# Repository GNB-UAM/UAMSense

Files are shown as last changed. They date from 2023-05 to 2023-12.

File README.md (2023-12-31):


# UAMSense electronic nose design
Artificial nose design with multimodal sensing capabilities.

___These are experimental designs. Use at your own risk.___

Please see Bibtex and other citation options at the bottom of the page.

UAMSense 4
==========

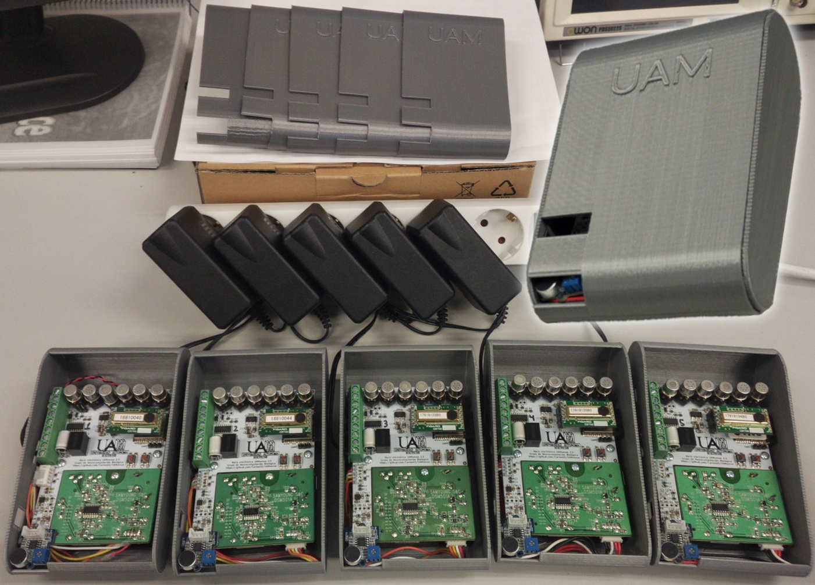
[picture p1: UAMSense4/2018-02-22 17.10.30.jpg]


UAMSense 3
==========

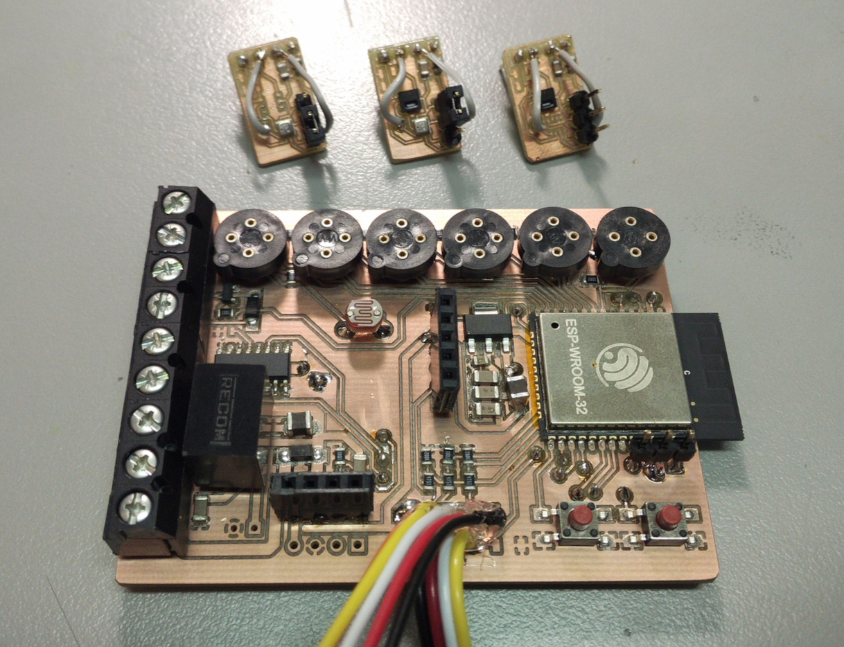
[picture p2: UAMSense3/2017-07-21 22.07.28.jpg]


UAMSense 2
==========

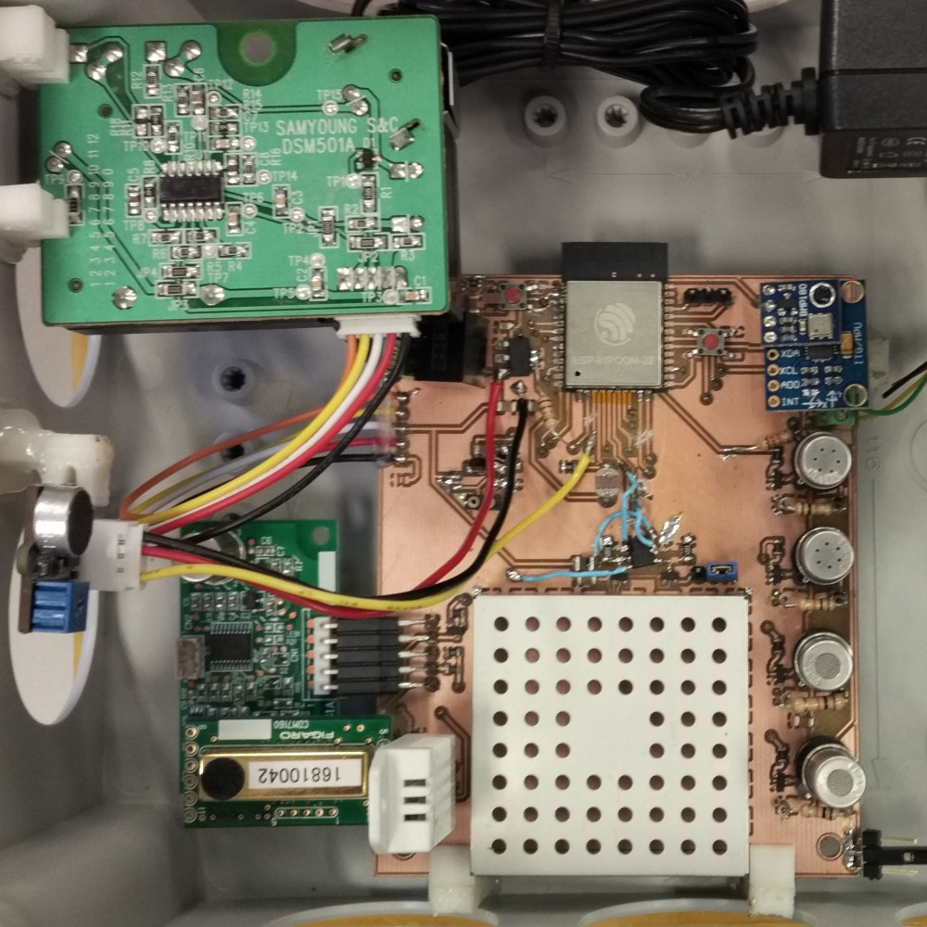
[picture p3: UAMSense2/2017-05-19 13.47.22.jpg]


UAMSense 1
==========

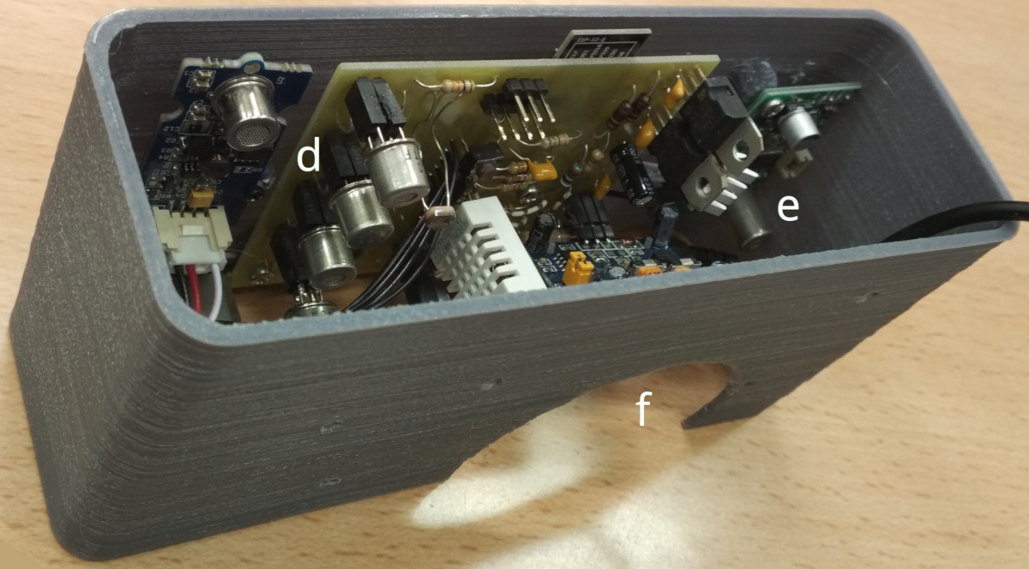
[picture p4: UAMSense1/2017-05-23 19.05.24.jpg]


UART-BME680
===========

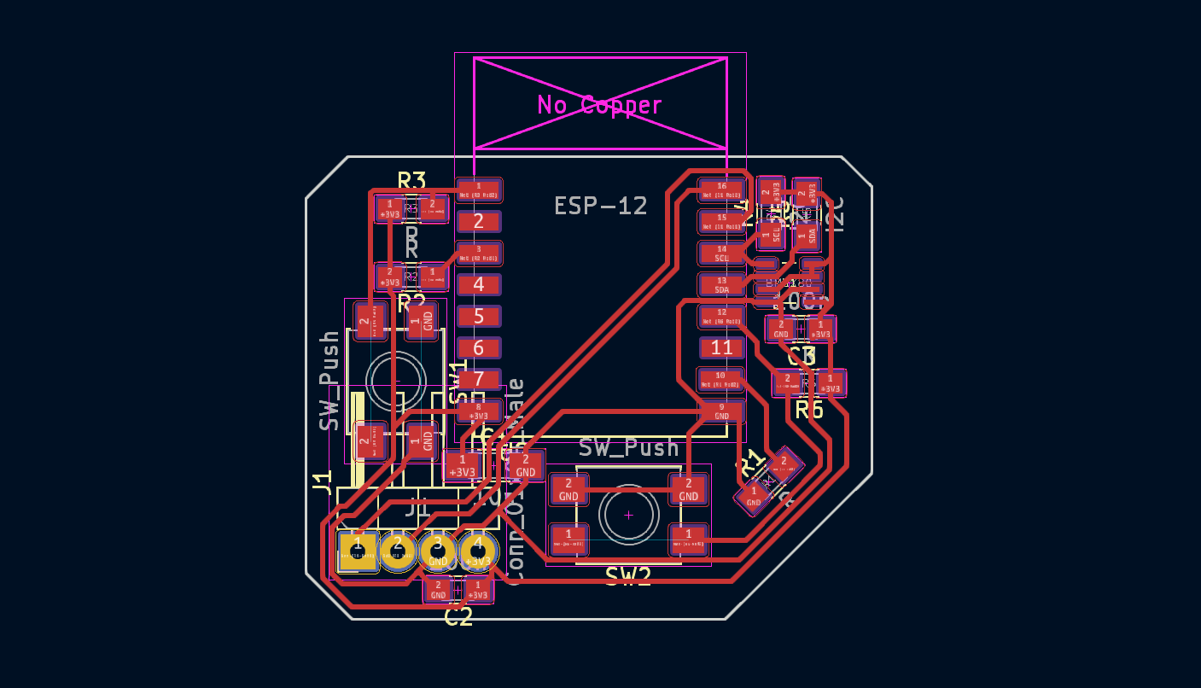
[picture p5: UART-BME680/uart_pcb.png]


I2C-Sensors
===========

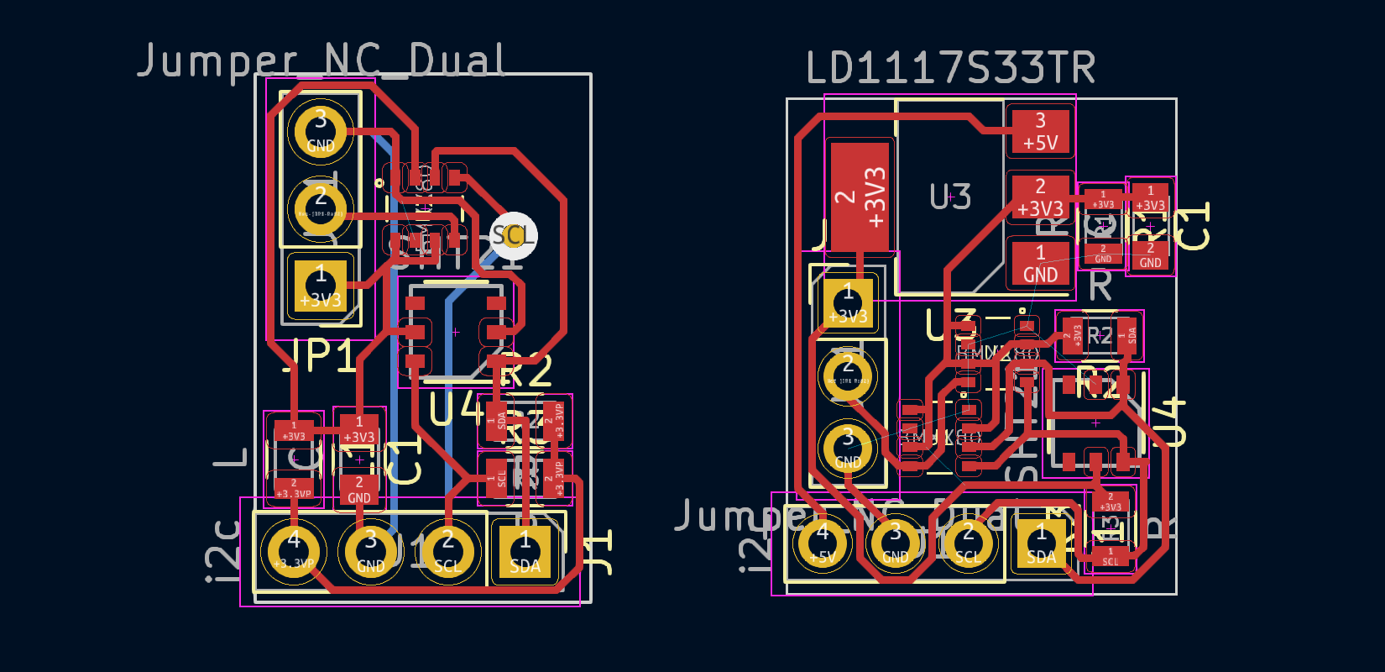
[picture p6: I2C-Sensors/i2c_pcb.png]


License
=======
For source code: GPLv3 <https://www.gnu.org/licenses/gpl-3.0.en.html>

For hardware: Attribution-ShareAlike 4.0 International <https://creativecommons.org/licenses/by-sa/4.0/>

© Carlos Garcia-Saura 2023

Cite as
=======

Scientific papers:
- Garcia-Saura C., Rodriguez-Lujan I., Serrano E., Rodríguez F.B. and Varona P., At-home monitorization using artificial noses
and multimodal sensors: a noninvasive approach to human routine certification. IBJ Plus 2022 1(s5) e00017. DOI: 10.24217/2531-
0151.22v1s5.00017. https://doi.org/10.24217/2531-0151.22V1S5.00017

PhD Thesis:
```bibtex
@phdthesis{garciasaura2023,
  title={Exploration and characterization of environments under uncertainty using multimodal sensors},
  author={Garcia-Saura, Carlos},
  year={2023},
  school={Escuela Politecnica Superior, Universidad Autonoma de Madrid}
}
```

UAMSense project (this repository):
```bibtex
@misc{uamsense2023,
  author = {Garcia-Saura, Carlos},
  title = {UAMSense electronic nose design},
  publisher = {GitHub},
  year = {2023},
  doi = {10.5281/ZENODO.10442698},
  url = {https://doi.org/10.5281/zenodo.10442698}
}
```

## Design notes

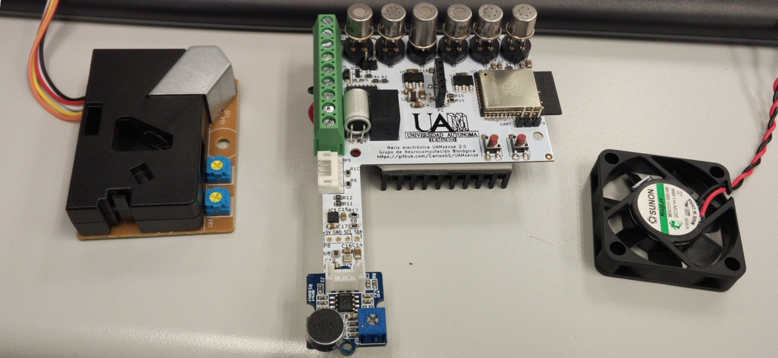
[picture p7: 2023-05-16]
UAMSense4/2017-09-22 19.42.48.jpg

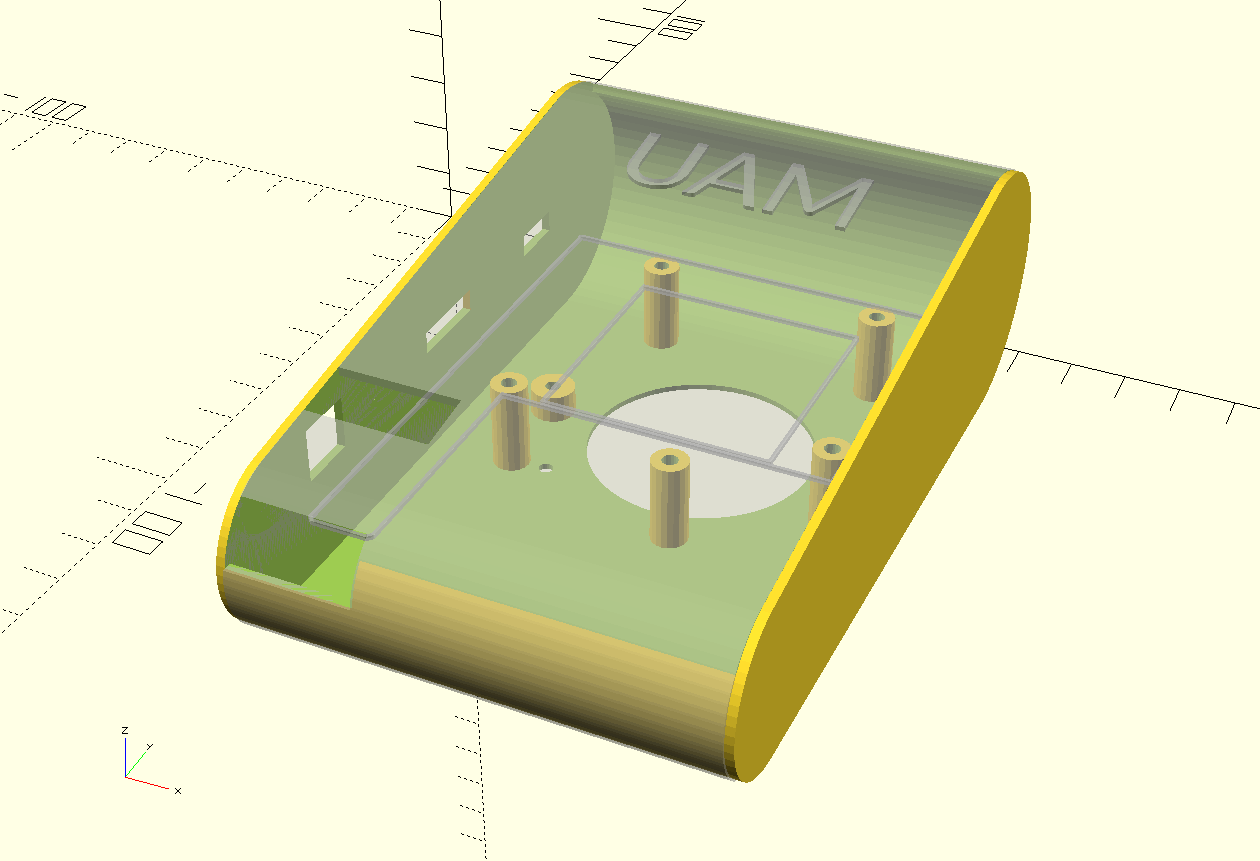
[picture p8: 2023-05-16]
UAMSense4/3Dprinted_enclosure/enclosure3D.png

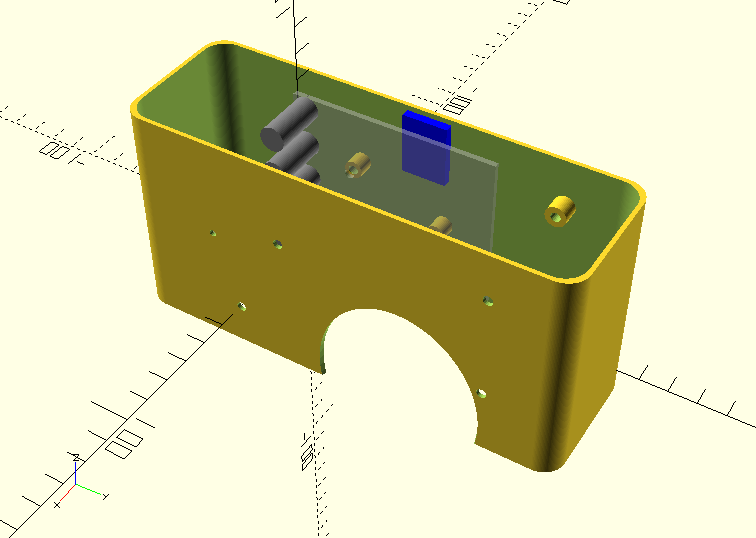
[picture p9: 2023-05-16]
UAMSense1/3Dprinted_enclosure/case.png

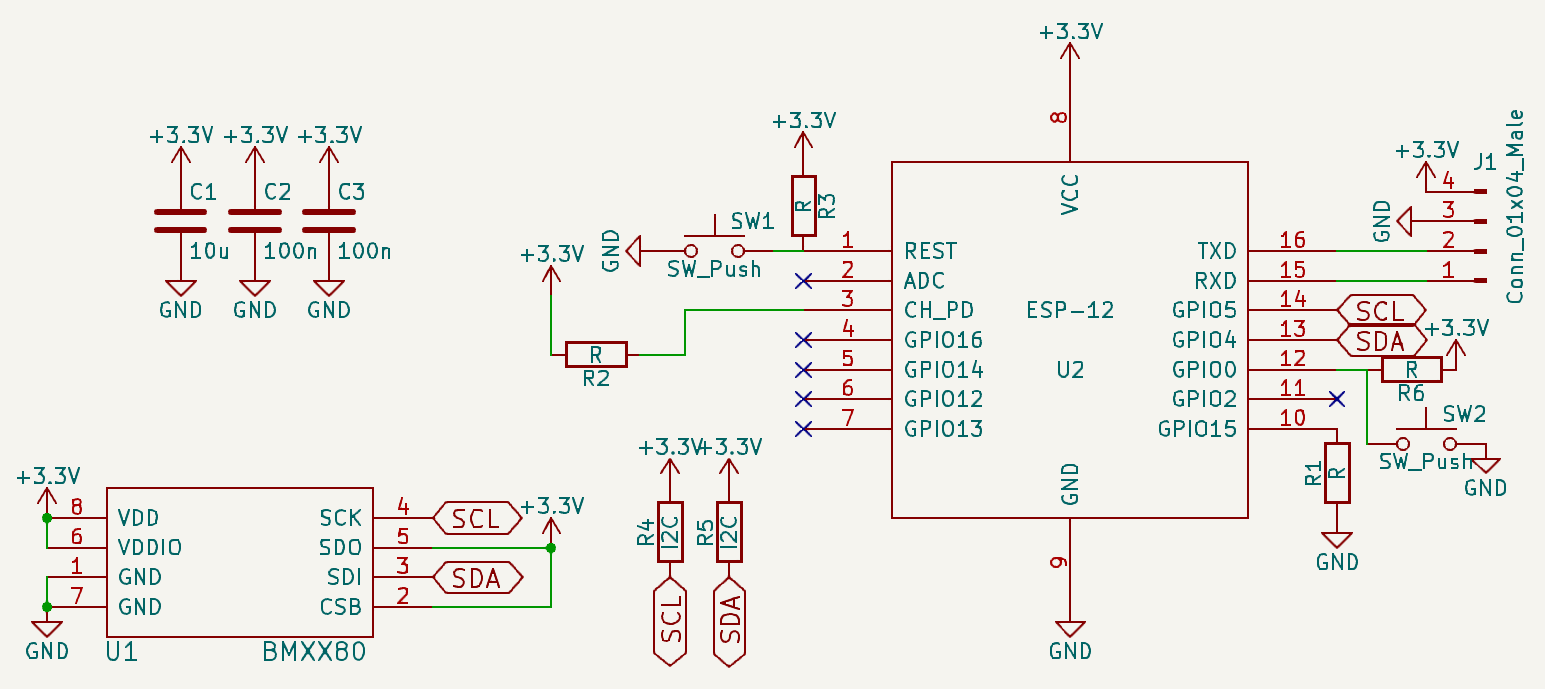
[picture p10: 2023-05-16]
UART-BME680/uart_sch.png

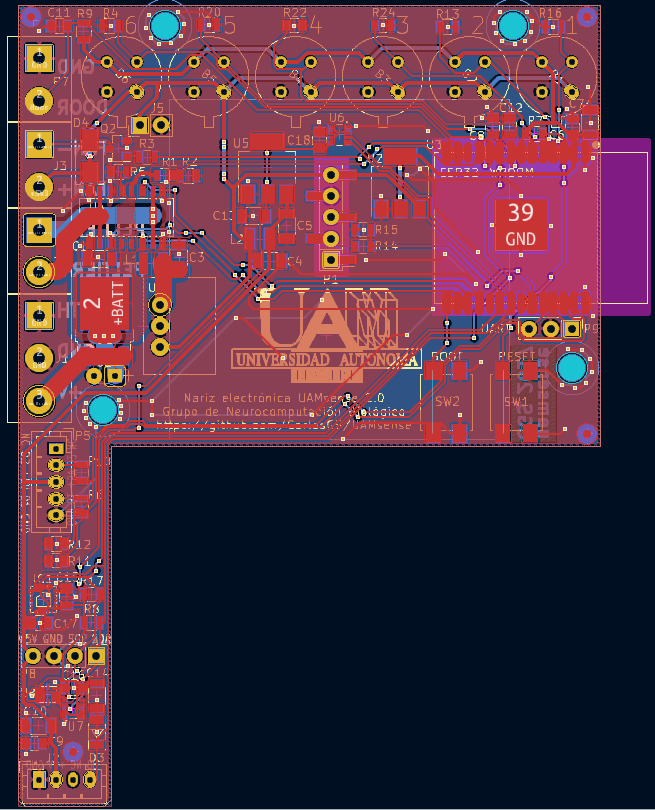
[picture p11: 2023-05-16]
UAMSense4/uamsense4_pcb.png

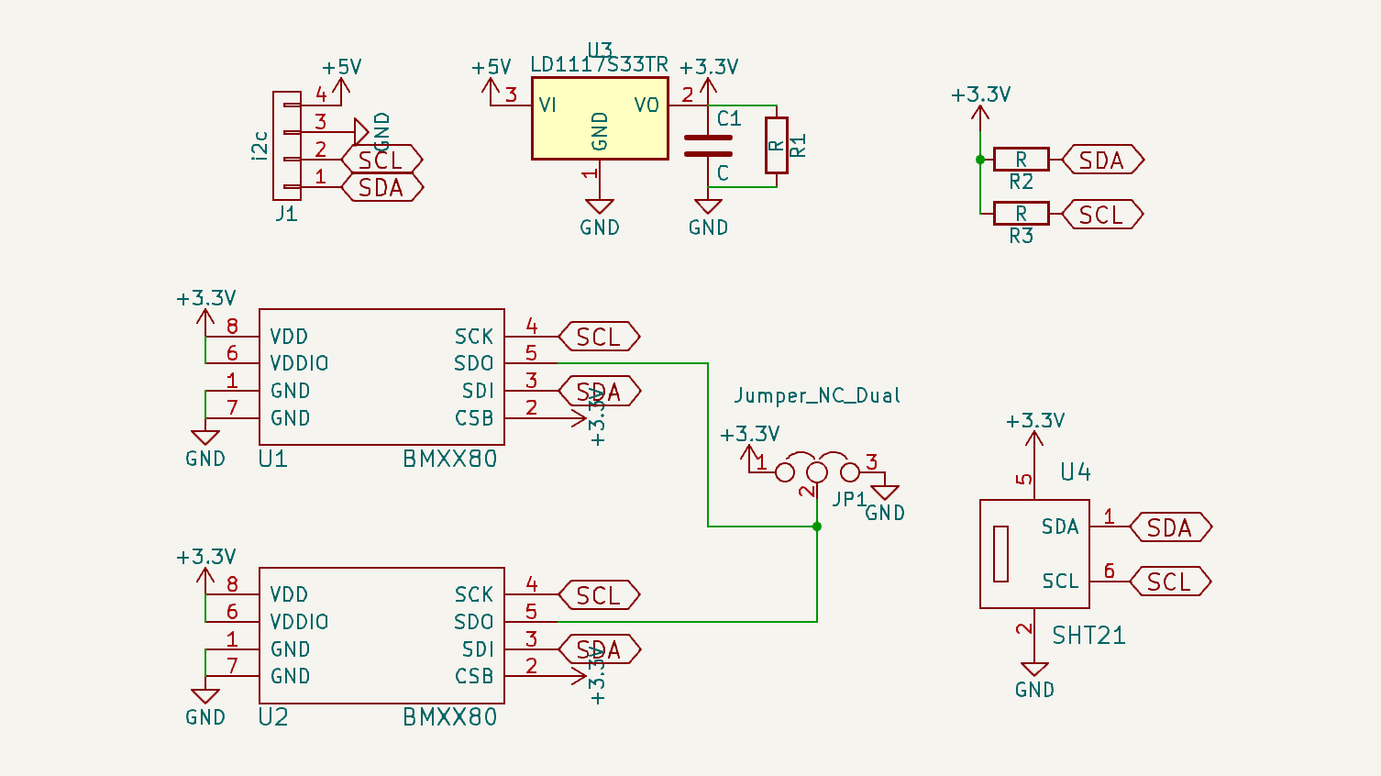
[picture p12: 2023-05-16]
I2C-Sensors/i2c_sch.png

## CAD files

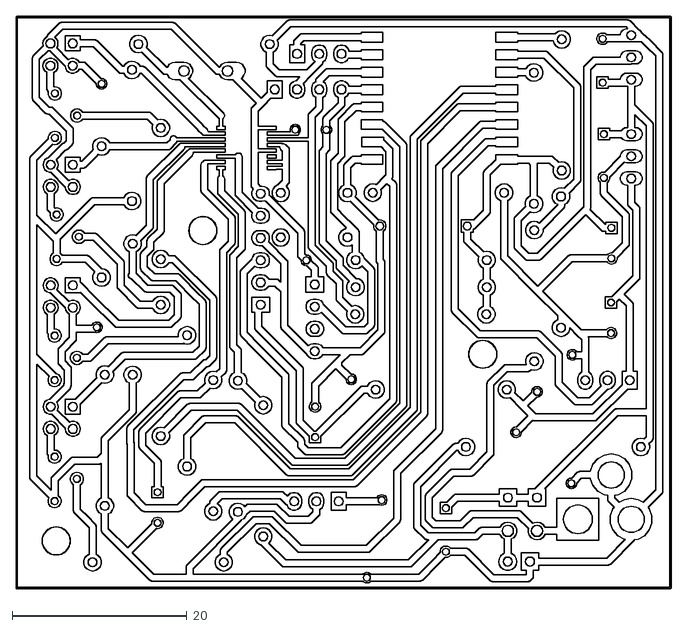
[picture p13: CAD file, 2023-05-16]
UAMSense1/3Dprinted_enclosure/sensors-B.Cu.dxf
74.9 x 65.4

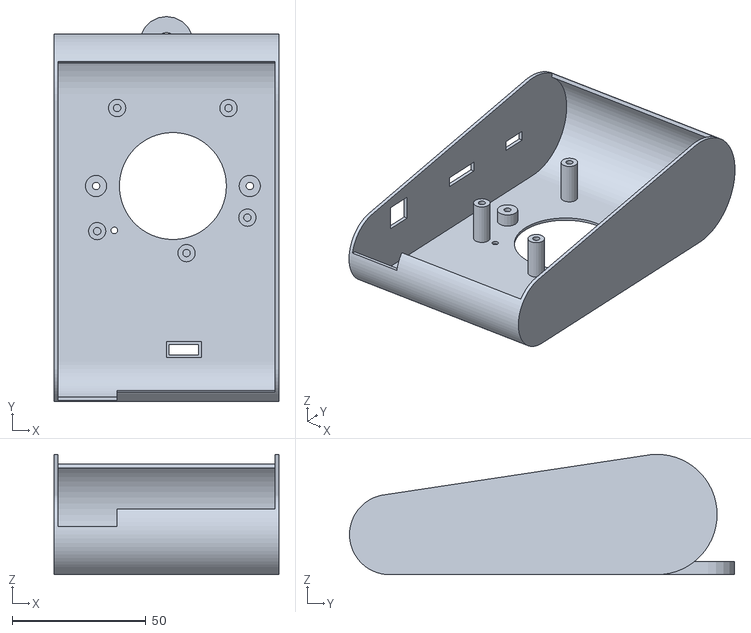
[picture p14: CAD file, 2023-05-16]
UAMSense4/3Dprinted_enclosure/enclosure.stl
84.0 x 144.0 x 45.0

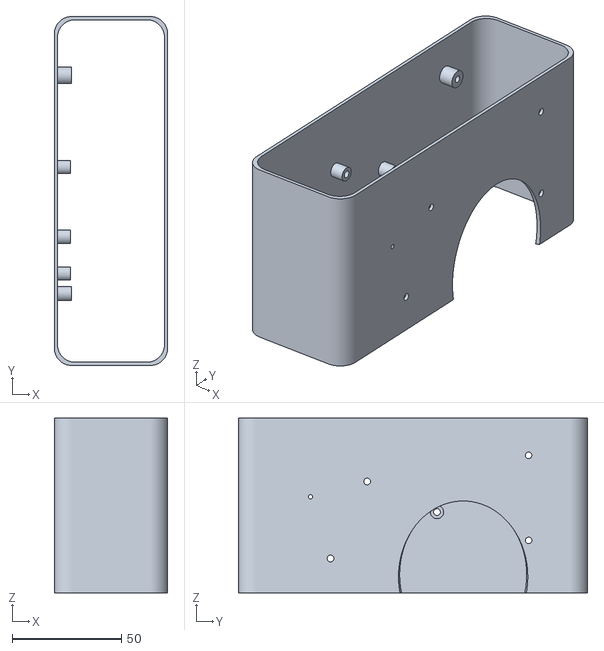
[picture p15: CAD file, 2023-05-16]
UAMSense1/3Dprinted_enclosure/case.stl
52.0 x 160.0 x 80.0

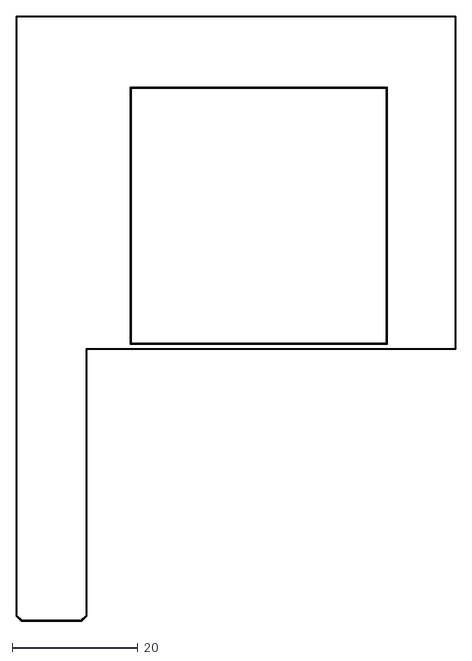
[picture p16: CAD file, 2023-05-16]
UAMSense4/3Dprinted_enclosure/uamsense-Edge.Cuts.dxf
69.8 x 96.0

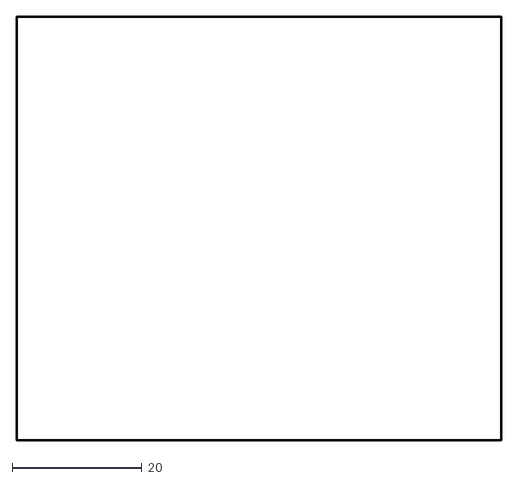
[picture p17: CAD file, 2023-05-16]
UAMSense1/3Dprinted_enclosure/sensors-Edge.Cuts.dxf
74.9 x 65.4

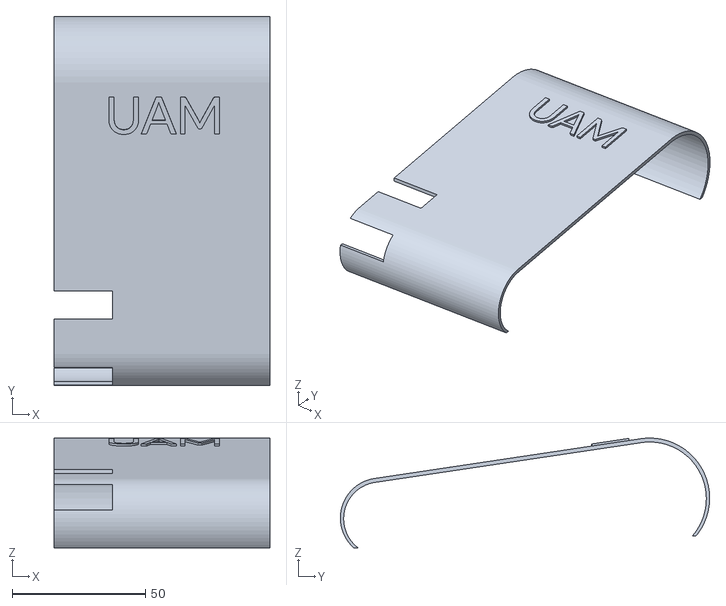
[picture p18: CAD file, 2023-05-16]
UAMSense4/3Dprinted_enclosure/lid.stl
81.0 x 138.5 x 41.2

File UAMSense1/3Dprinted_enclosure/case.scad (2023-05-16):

// UAMSense https://github.com/GNB-UAM/UAMSense
// (C) Carlos Garcia-Saura 2023

// Increase the resolution of default shapes
$fa = 5; // Minimum angle for fragments [degrees]
$fs = 0.5; // Minimum fragment size [mm]




module translate_mainBoard(move = true) {
    if(move)
    translate([0,74,0])
    rotate([0,0,90]) rotate([90,0,0])
    translate([-114,94,0])
    children();
    else children();
}

module pir_hole() {
    // hole for the PIR sensor
    translate_mainBoard(true)
    translate([93+12,-67,3]) rotate([30,0,0]) cylinder(r1=30/2, r2=90/2, h=100);
}

module mainBoard(drills = false, move=true, incD=0, incH=0, drillH=30, centerDrills=false) {
    translate_mainBoard(move)
    if(!drills) {
        //color("black") translate([0,0,3]) import("sensors-B.Cu.dxf");
        
        // ESP12
        color("blue") translate([80,-45,-3]) cube([16,22,3]);
        
        // TGS sensors
        color("gray") translate([44.8,-32.5,2]) cylinder(r=9/2, h=20);
        color("gray") translate([44.8,-32.5-13.9,2]) cylinder(r=9/2, h=20);
        color("gray") translate([44.8,-32.5-13.9*2,2]) cylinder(r=9/2, h=20);
        color("gray") translate([44.8,-32.5-13.9*3,2]) cylinder(r=9/2, h=20);
        
        difference() {
            hull() linear_extrude(height=2) import("sensors-Edge.Cuts.dxf");
            mainBoard(drills = true, move=false, incD=incD, incH=incH);
        }
    } else {
        translate([44.2,-88.3,3+incH]) rotate([180,0,0]) cylinder(h=drillH, r=incD+3.1/2, center=centerDrills);
        translate([61,-53,3+incH]) rotate([180,0,0]) cylinder(h=drillH, r=incD+3.1/2, center=centerDrills);
        translate([93,-67,3+incH]) rotate([180,0,0]) cylinder(h=drillH, r=incD+3.1/2, center=centerDrills);
    }
}

%mainBoard();

difference() {
    union() {
        difference() {
            translate([18,42,30]) bcube([52,160,80],cr=8,cres=30);
            translate([18,42,30]) bcube([52-3,160-3,81],cr=8,cres=30);
        }
        // Drill supports
        mainBoard(drills=true, incD=1.5, incH=-3.5, drillH=6);
        // air quality sensor
        translate([0,-5,34]) rotate([0,-90,0]) cylinder(h=7, r=2+2.5/2);
        // co2
        translate([0,95,14]) {
            rotate([0,-90,0]) cylinder(h=7, r=2+3.5/2);
            translate([0,0,39])
            rotate([0,-90,0]) cylinder(h=7, r=2+3.5/2);
        }
    }
    
    mainBoard();
    mainBoard(drills=true, centerDrills=true, drillH=150);
    pir_hole();

    // Hole for the dust sensor
    %translate([-5,-34]) cube([46.5, 32, 20]);

    // Drill for the air quality sensor
    translate([0,-5,34]) rotate([0,90,0]) cylinder(h=150, r=2/2, center=true);

    // Drills for the CO2 sensor
    translate([0,95,14]) {
        rotate([0,90,0]) cylinder(h=150, r=3/2, center=true);
        translate([0,0,39])
        rotate([0,90,0]) cylinder(h=150, r=3/2, center=true);
    }
}
    


// bcube module by Obijuan http://www.iearobotics.com/wiki/index.php?title=Objeto_3D:Cubo_Biselado
module bcube(size,cr=0,cres=0)
{
  //-- Internal cube size
  bsize = size - 2*[cr,cr,0];

  //-- Get the (x,y) coorner coordinates in the 1st cuadrant
  x = bsize[0]/2;
  y = bsize[1]/2;

  //-- A corner radius of 0 means a standar cube!
  if (cr==0)
    cube(bsize,center=true);
  else {

      
      //-- The height of minkowski object is double. So
      //-- we sould scale by 0.5
      scale([1,1,0.5])

      //-- This translation is for centering the minkowski objet
      translate([-x, -y,0])

      //-- Built the  beveled cube with minkowski
      minkowski() {

        //-- Internal cube
        cube(bsize,center=true);

        //-- Cylinder in the corner (1st cuadrant)
        translate([x,y, 0])
          cylinder(r=cr, h=bsize[2],center=true, $fn=4*(cres+1));
      }
  }

}

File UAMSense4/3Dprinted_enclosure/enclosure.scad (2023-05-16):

// UAMSense https://github.com/GNB-UAM/UAMSense
// (C) Carlos Garcia-Saura 2023

%translate([0,0,16]) linear_extrude(height=0.8) offset(0.25) import("uamsense-Edge.Cuts.dxf"); 

$fn=20;

screw_radius = 2.8/2;

module board_pillars(r=3.2/2, h=10) {
    translate([58.039, -24.232]) cylinder(r=r, h=h);
    translate([99.695, -24.257]) cylinder(r=r, h=h);
    translate([50.576, -70.272]) cylinder(r=r, h=h);
    translate([106.756, -65.227]) cylinder(r=r, h=h);
    
    translate([110-26, -74.5-4]) cylinder(r=r, h=h-0.5);
}

module fan_pillars(r=3.2/2, h=10) {
    translate(fan_center) {
        translate([57.5/2,0,0]) cylinder(r=r, h=h);
        translate([-57.5/2,0,0]) cylinder(r=r, h=h);
    }
}

module fan_pillars_(r=3.2/2, h=10) {
    translate(fan_center)
        for(i = [0:3])
            rotate([0,0,i*90])
                translate([45.5/2,0,0]) cylinder(r=r, h=h);
}

fan_center = [78.9,-53.4,0];





module box() {
    difference() {
        union() {
            hull() {
                translate([34.5,-19,45/2-1]) rotate([0,90,0]) cylinder(r=45/2, h=84, $fn=60);
                translate([34.5,-103-16,30/2-1]) rotate([0,90,0]) cylinder(r=30/2, h=84, $fn=60);
            }
            translate([34.5+84/2,-20,-1]) hull() {
                cylinder(r=20/2,h=5);
                translate([0,20,0]) cylinder(r=20/2,h=5);
            }
        }
        hull() {
            translate([35+1,-19,45/2-1.25+0.01]) rotate([0,90,0]) cylinder(r=45/2-1.25, h=83-2, $fn=60);
            translate([35+1,-103-16,30/2-1.25+0.01]) rotate([0,90,0]) cylinder(r=30/2-1.25, h=83-2, $fn=60);
        }
        translate([34.5+84/2,0,-1-0.1]) cylinder(r=8/2,h=5.2);
    }
}

module lid() {
    elongation = 0.5;
    difference() {
        hull() {
            translate([34.5+1.5,-19+elongation,45/2-1]) rotate([0,90,0]) cylinder(r=45/2, h=84-3, $fn=60);
            translate([34.5+1.5,-103-16-elongation,30/2-1]) rotate([0,90,0]) cylinder(r=30/2, h=84-3, $fn=60);
        }
        hull() {
            translate([34,-19+elongation,45/2-1.25+0.01]) rotate([0,90,0]) cylinder(r=45/2-1.25, h=85, $fn=60);
            translate([34,-103-16-elongation,30/2-1.25+0.01]) rotate([0,90,0]) cylinder(r=30/2-1.25, h=85, $fn=60);
        }
        translate([35.9,-109.5,24]) cube([22,10.5,30]); // Hole for light sensor (top)
        translate([35.9,-140,17]) cube([22,30,9.5]); // Hole for microphone
        translate([75,-65,-15]) rotate([2,0,0]) cube([150,200,40],center=true);
    }
    translate([55,-40,40.8]) rotate([8.5,0,0]) linear_extrude(height = 1)
        text("UAM", font = "Lato Medium", size = 14, direction = "ltr", spacing = 1 );
}

difference() {
    union() {
        box();
        board_pillars(r=6.5/2, h=16);
        fan_pillars(r=8/2, h=5);
        translate([51.5+25,-117.6,0]) cube([13,6,0.5]); // dust sensor air inlet
    }
    translate([0,0,6]) board_pillars(r=screw_radius, h=16);
    translate([0,0,-2]) fan_pillars(r=screw_radius, h=9);
    translate([51.5+26,-116.6,-2]) cube([11,4,4]); // dust sensor air inlet
    
    translate([57,-70,-2]) cylinder(r=2.5/2, h=6); // Hole for fan cable
    translate([0,0,-2]) translate(fan_center) cylinder(r=40/2, h=6, $fn=60); // Hole for fan
    translate([36,-140,17]) cube([22,30,9.5]); // Hole for microphone
    translate([25,-109.5,17]) cube([21.5,10.5,9.5]); // Hole for light sensor (bottom)
    difference() { // holes for cables
        translate([30,-72,19]) cube([15,46,4]);
        translate([29,-72+3*46/9,18]) cube([17,4*46/9,6]);
    }
    hull() { // hole for lid
            translate([35+1,-19,45-1-0.6]) rotate([0,90,0]) cylinder(r=25/2, h=83-2, $fn=60);
            translate([35+1,-103-16,30-1-0.6]) rotate([0,90,0]) cylinder(r=25/2, h=83-2, $fn=60);
    }
}

%lid();

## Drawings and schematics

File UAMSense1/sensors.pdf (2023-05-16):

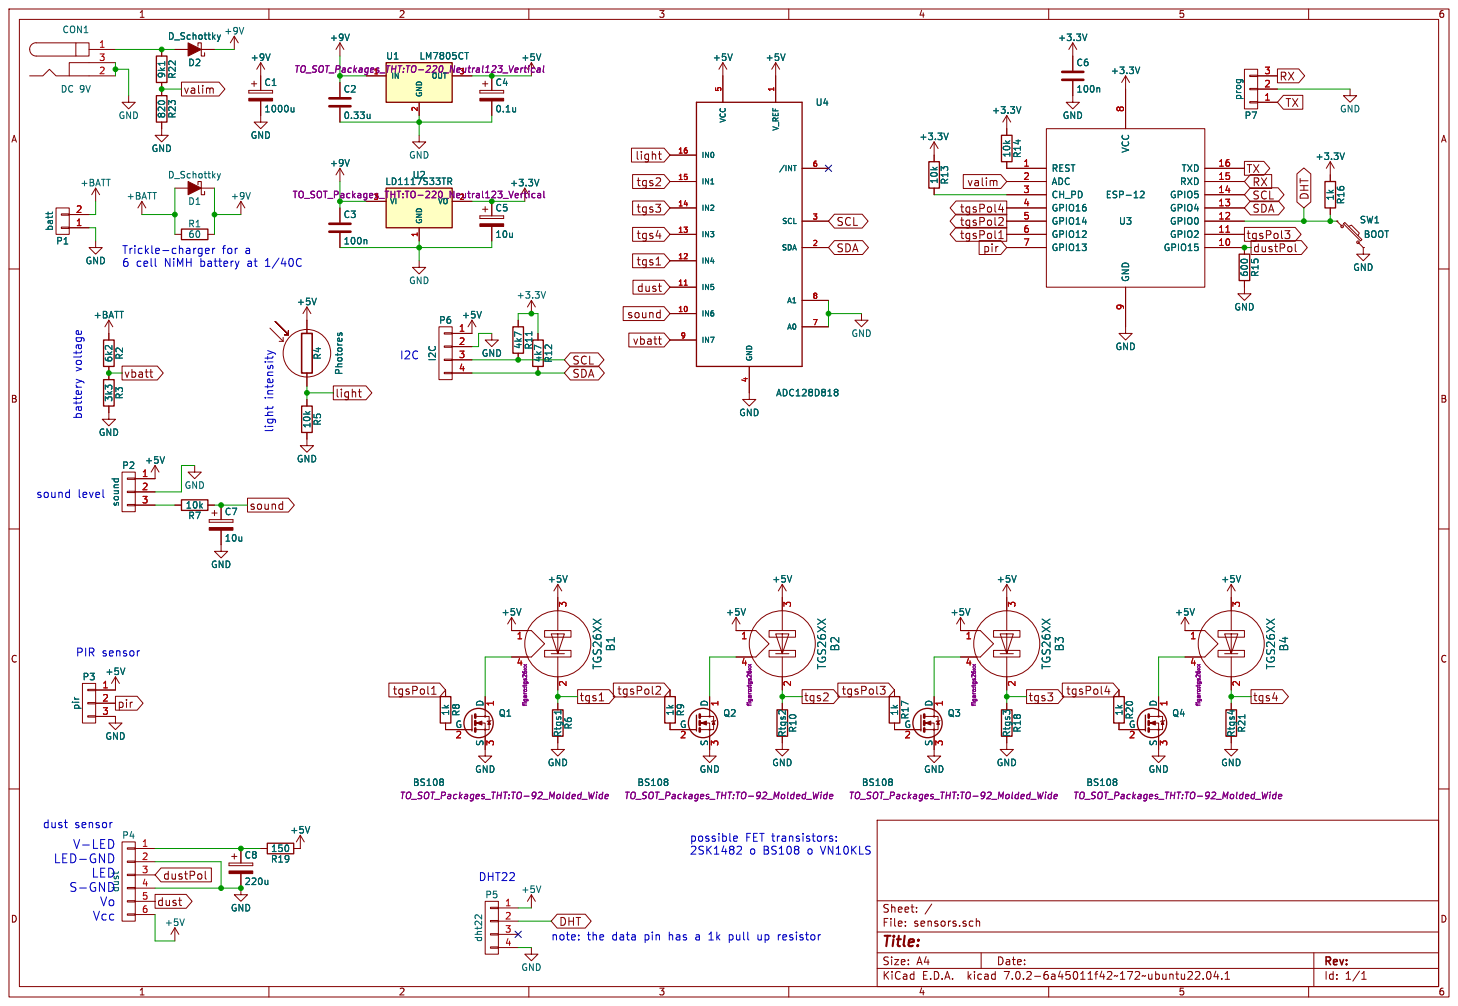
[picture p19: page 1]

6 cell NiMH battery at 1/40C

3 GND GND 1kR9 +5V R18 Rtgs3 GND R17 1k GND Q3 BS108 TO_SOT_Packages_THT:TO-92_Molded_Wide D

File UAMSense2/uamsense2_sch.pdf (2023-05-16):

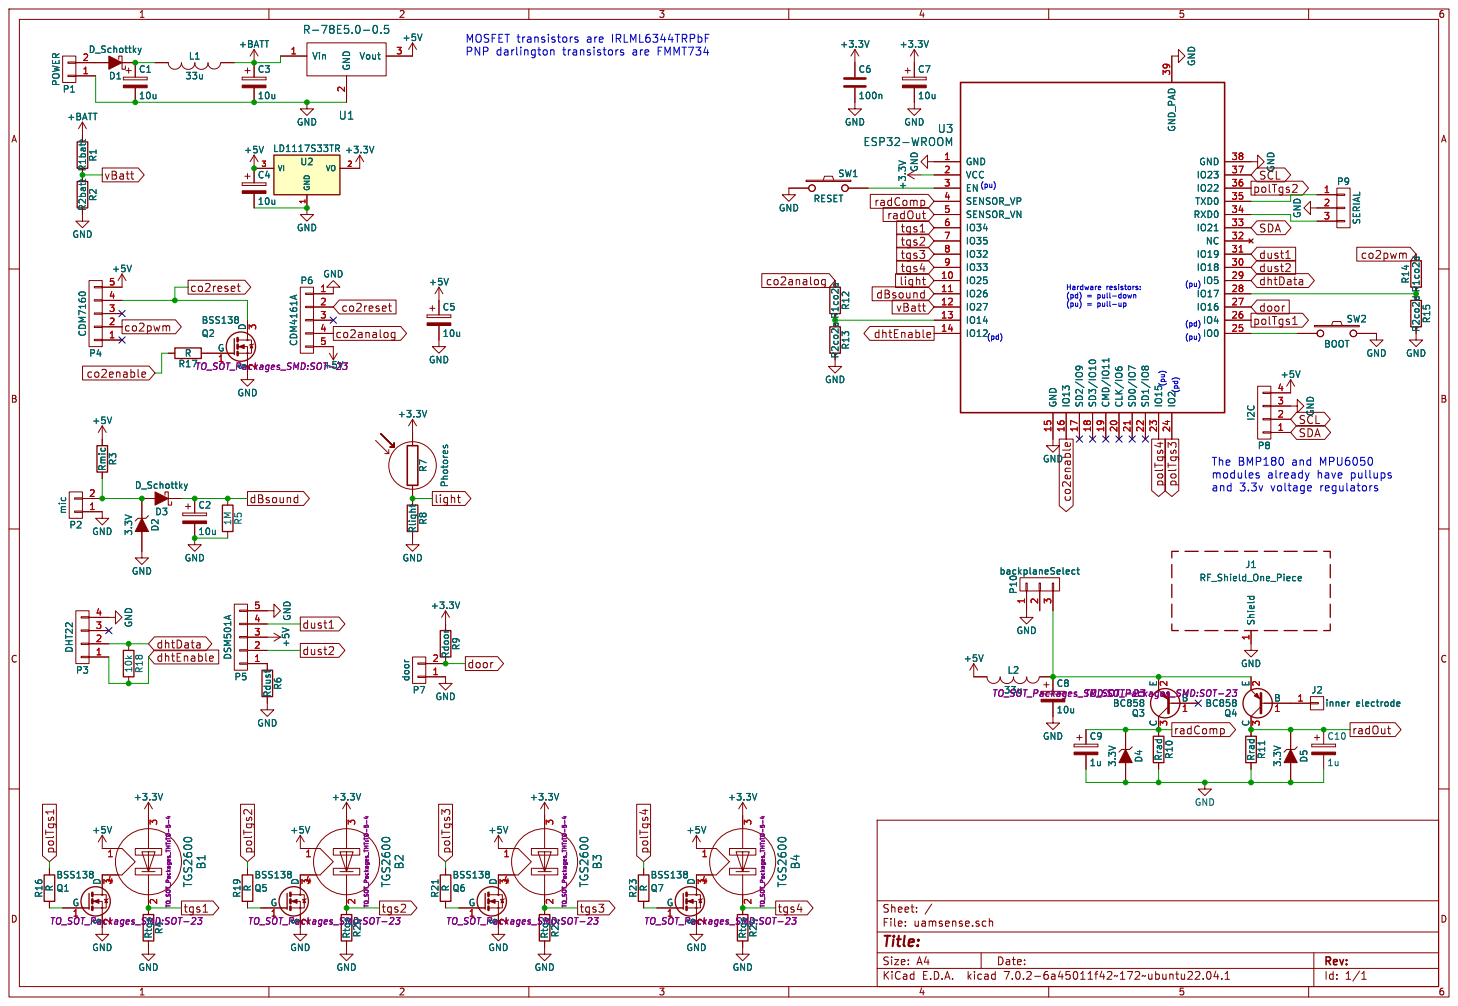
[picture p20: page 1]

3 +5V R23R GNDRtgs R22 Rtgs R24 GND GND

4 Q6 BSS138 TO_SOT_Packages_SMD:SOT-23 G
Id: 1/1 Title: File: uamsense.sch Sheet: / R21R

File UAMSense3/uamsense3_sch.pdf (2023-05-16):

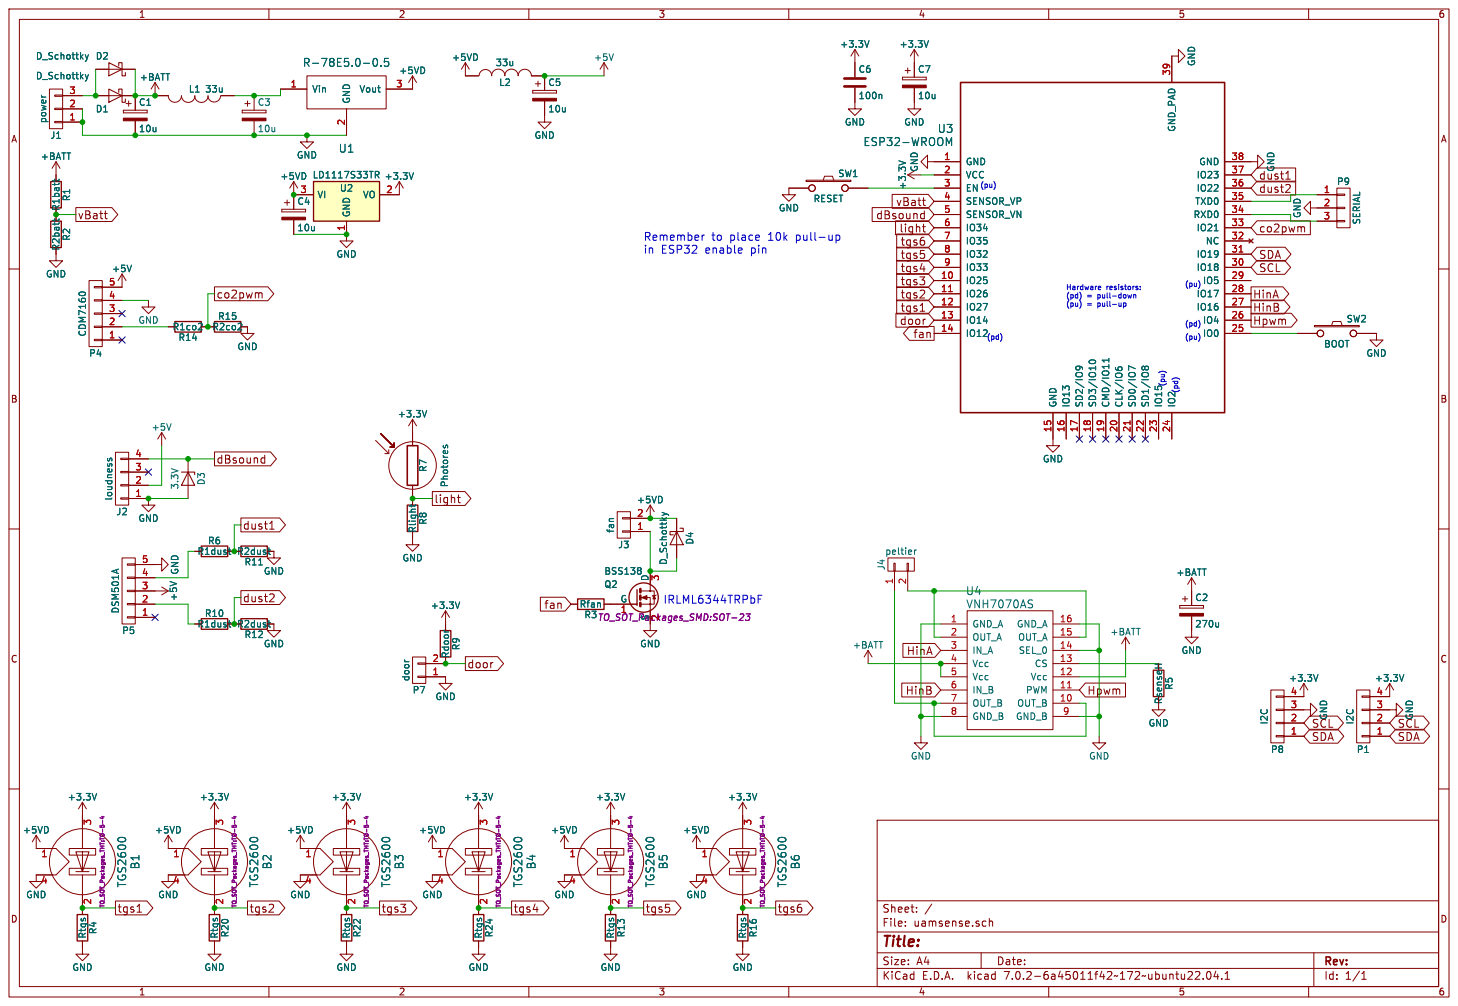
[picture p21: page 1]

(pu) (pd) Remember to place 10k pull-up

Hardware resistors: (pd) = pull-down

Id: 1/1 Title: File: uamsense.sch Sheet: / +5VD

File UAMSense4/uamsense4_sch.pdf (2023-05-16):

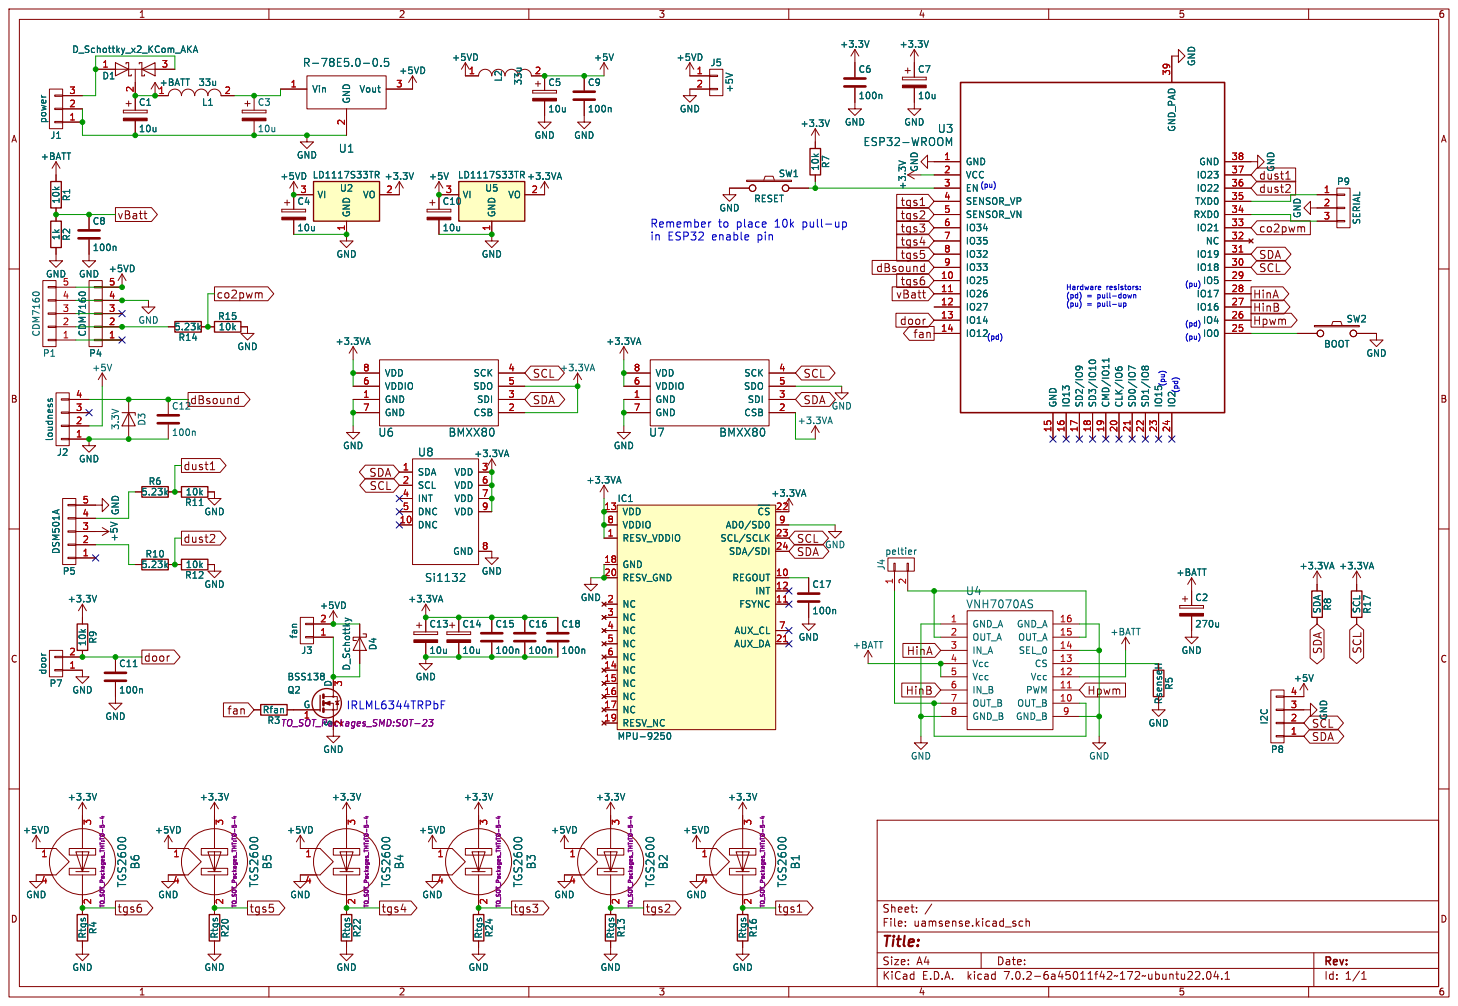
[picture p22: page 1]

(pd) (pd) Remember to place 10k pull-up
in ESP32 enable pin

Hardware resistors: (pd) = pull-down

Id: 1/1 Title: File: uamsense.kicad_sch Sheet: / C18

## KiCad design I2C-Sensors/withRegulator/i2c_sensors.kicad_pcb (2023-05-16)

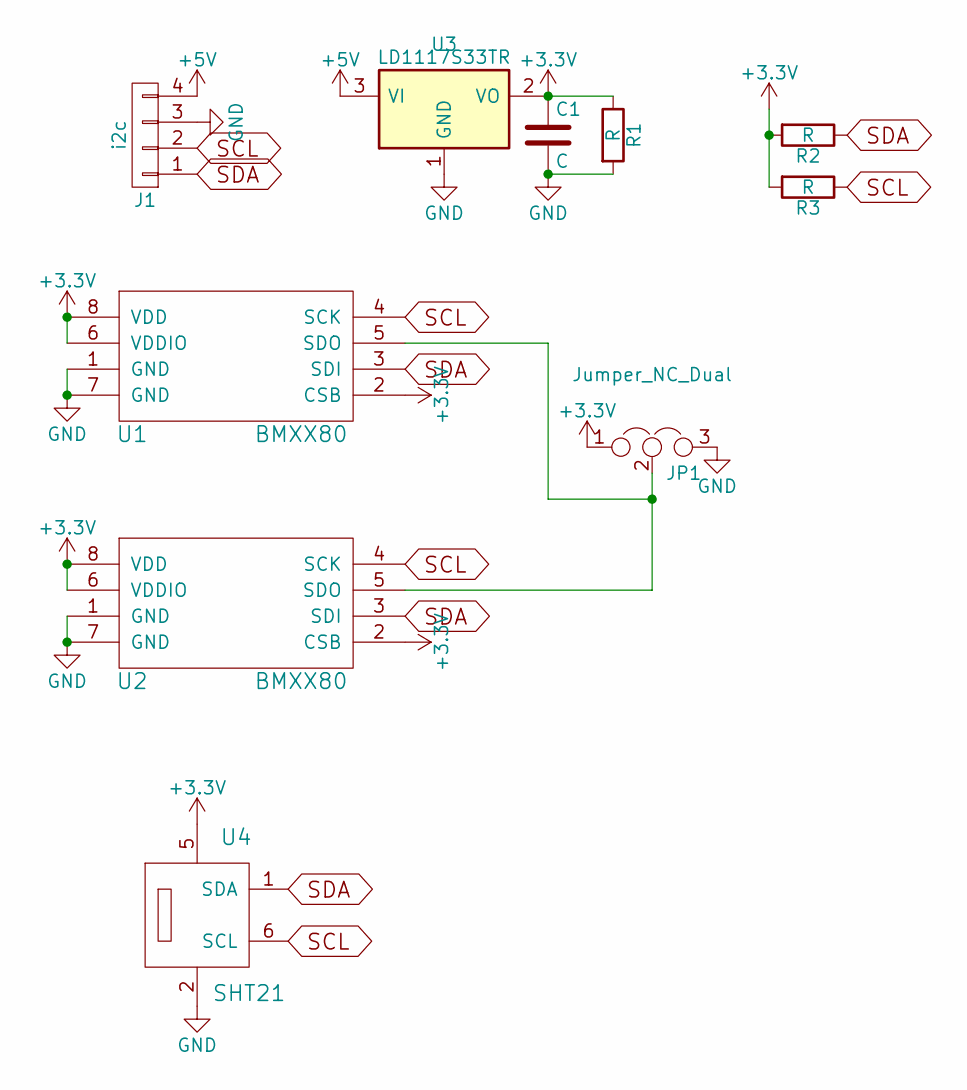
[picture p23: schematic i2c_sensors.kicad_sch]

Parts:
C1: C; C_0805
J1: i2c; Pin_Header_Straight_1x04_Pitch2.54mm
JP1: Jumper_NC_Dual; Pin_Header_Straight_1x03_Pitch2.54mm
R1, R2, R3: R; R_0805
U1, U2: BMXX80; BME280
U3: LD1117S33TR; SOT-223
U4: SHT21; DFN-6-1EP_3x3mm_Pitch0.95mm

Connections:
+3V3: C1.1, JP1.1, R1.1, R2.2, R3.2, U1.2 (CSB), U1.6 (VDDIO), U1.8 (VDD), U2.2 (CSB), U2.6 (VDDIO), U2.8 (VDD), U3.2 (VO), U4.5
+5V: J1.4, U3.3 (VI)
GND: C1.2, J1.3, JP1.3, R1.2, U1.1 (GND), U1.7 (GND), U2.1 (GND), U2.7 (GND), U3.1 (GND), U4.2
unnamed: JP1.2, U1.5 (SDO), U2.5 (SDO)
SCL: J1.2, R3.1, U1.4 (SCK), U2.4 (SCK), U4.6 (SCL)
SDA: J1.1, R2.1, U1.3 (SDI), U2.3 (SDI), U4.1 (SDA)

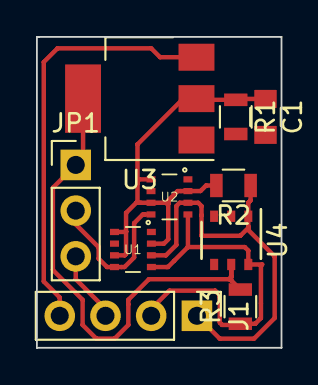
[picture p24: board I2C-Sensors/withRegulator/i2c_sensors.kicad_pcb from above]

Board: 2 copper layers, 13.6 x 17.3 mm, 10 parts (0 on the bottom side), 6 nets.

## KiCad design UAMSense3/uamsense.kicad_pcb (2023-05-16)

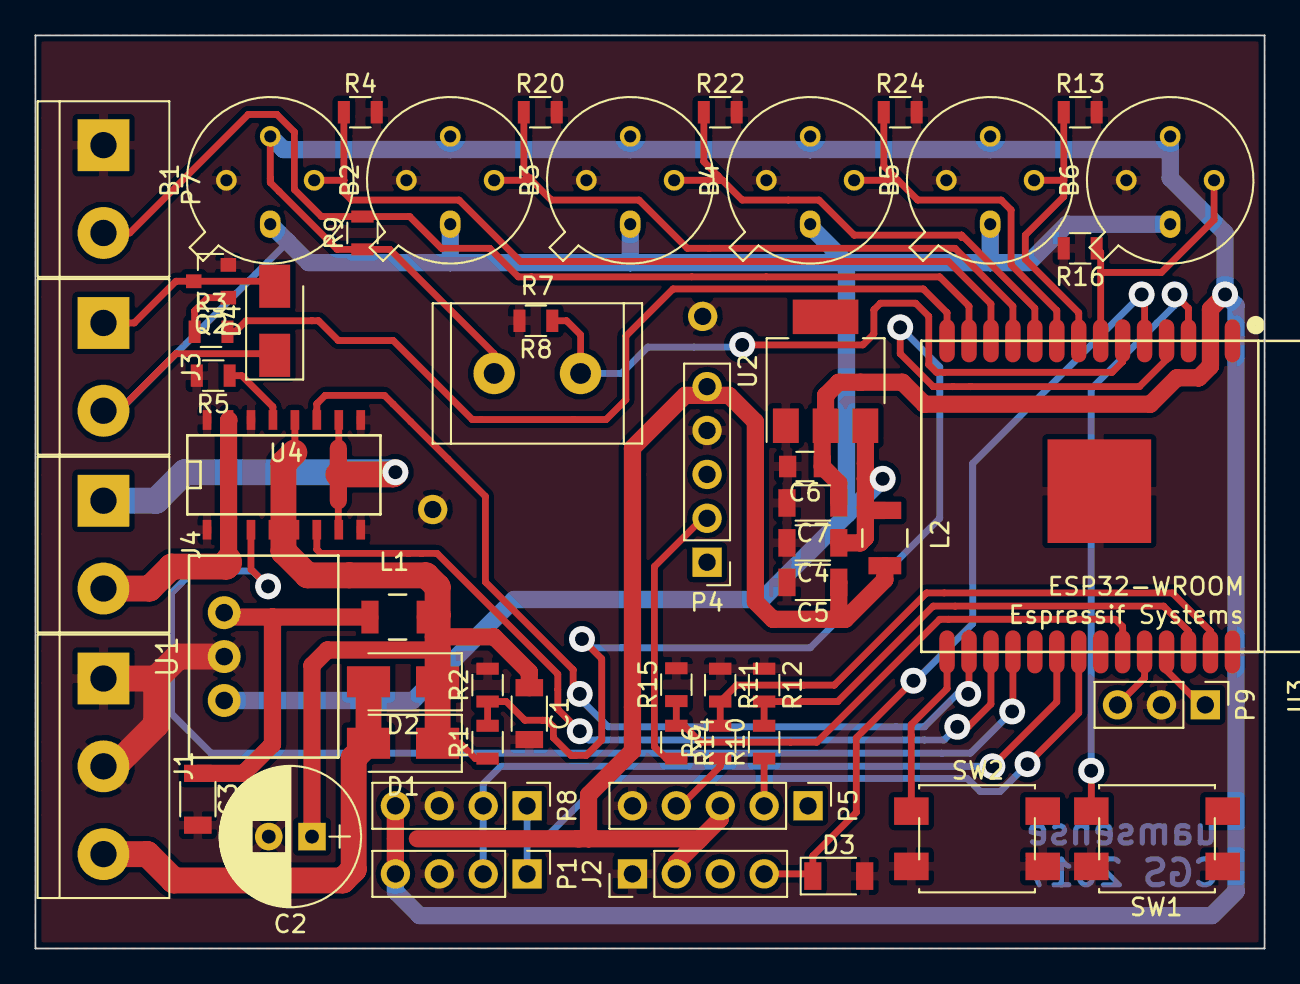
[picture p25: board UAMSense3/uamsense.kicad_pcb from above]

Board: 2 copper layers, 71.1 x 52.8 mm, 57 parts (0 on the bottom side), 38 nets.

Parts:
B1, B2, B3, B4, B5, B6: TGS2600; TO-5-4
C1, C3, C4, C5, C7: 10u; C_1206
C2: 270u; CP_Radial_D8.0mm_P2.50mm
C6: 100n; C_0805
D1, D2, D4: D_Schottky; D_SMA
D3: 3.3V; D_1206
J1: power; bornier3
J2, J2#2, J2#3: loudness; Pin_Header_Straight_1x04_Pitch2.54mm
J3: fan; bornier2
J4: peltier; bornier2
L1, L2: 33u; Neosid_Inductor_SM-NE30_SMD1210
P1: I2C; Socket_Strip_Straight_1x04_Pitch2.54mm
P4: CDM7160; Socket_Strip_Straight_1x05_Pitch2.54mm
P5: DSM501A; Socket_Strip_Straight_1x05_Pitch2.54mm
P7: door; bornier2
P8: I2C; Pin_Header_Straight_1x04_Pitch2.54mm
P9: SERIAL; Pin_Header_Straight_1x03_Pitch2.54mm
Q2: BSS138; SOT-23
R1: R1batt; R_0805
R2: R2batt; R_0805
R3: Rfan; R_0805
R4, R13, R16, R20, R22, R24: Rtgs; R_0805
R5: RsenseH; R_0805
R6, R10: R1dust; R_0805
R7: Photores; R_Radial_Power_L12.0mm_W8.0mm_P5.00mm
R8: Rlight; R_0805
R9: Rdoor; R_0805
R11, R12: R2dust; R_0805
R14: R1co2; R_0805
R15: R2co2; R_0805
SW1: RESET; smd_button
SW2: BOOT; smd_button
U1: R-78E5.0-0.5
U2: LD1117S33TR; SOT-223
U3: ESP32-WROOM
U4: VNH7070AS; SO-16-N

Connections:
+3V3: B1.3, B2.3, B3.3, B4.3, B5.3, B6.3, C6.1, C7.1, P1.4, P8.4, R7.1, R9.1, U2.2, U3.2
+5V: C5.1, J2#3.2, L2.2, P4.5, P5.3
+5VD: B1.1, B2.1, B3.1, B4.1, B5.1, B6.1, C4.1, D4.1, J3.2, L2.1, U1.3, U2.3
+BATT: C1.1, C2.1, D1.1, D2.1, L1.2, R1.1, U4.4, U4.5, U4.12
GND: B1.4, B2.4, B3.4, B4.4, B5.4, B6.4, C1.2, C2.2, C3.2, C4.2, C5.2, C6.2, C7.2, D3.2, J1.1, J1.2, J2.1, J2#2.1, J2#3.1, P1.3, P4.4, P5.5, P7.1, P8.3, P9.2, Q2.2, R2.2, R4.2, R5.2, R8.2, R11.1, R12.1, R13.2, R15.2, R16.2, R20.2, R22.2, R24.2, SW1.1, SW2.2, U1.2, U2.1, U3.1, U3.38, U3.39, U4.1, U4.8, U4.9, U4.14, U4.16
HinA: U3.28, U4.3
HinB: U3.27, U4.6
Hpwm: U3.26, U4.11
unnamed: C3.1, L1.1, U1.1
unnamed: D1.2, D2.2, J1.3
unnamed: D4.2, J3.1, Q2.3
unnamed: J4.1, U4.7, U4.10
unnamed: J4.2, U4.2, U4.15
unnamed: P4.2, R14.2
unnamed: P5.2, R10.1
unnamed: P5.4, R6.1
unnamed: P9.1, U3.35
unnamed: P9.3, U3.34
unnamed: Q2.1, R3.1
unnamed: R5.1, U4.13
unnamed: SW1.2, U3.3
unnamed: SW2.1, U3.25
SCL: P1.2, P8.2, U3.30
SDA: P1.1, P8.1, U3.31
co2pwm: R14.1, R15.1, U3.33
dBsound: D3.1, J2#3.4, U3.5
door: P7.2, R9.2, U3.13
dust1: R6.2, R11.2, U3.37
dust2: R10.2, R12.2, U3.36
fan: R3.2, U3.14
light: R7.2, R8.1, U3.6
tgs1: B1.2, R4.1, U3.12
tgs2: B2.2, R20.1, U3.11
tgs3: B3.2, R22.1, U3.10
tgs4: B4.2, R24.1, U3.9
tgs5: B5.2, R13.1, U3.8
tgs6: B6.2, R16.1, U3.7
vBatt: R1.2, R2.1, U3.4

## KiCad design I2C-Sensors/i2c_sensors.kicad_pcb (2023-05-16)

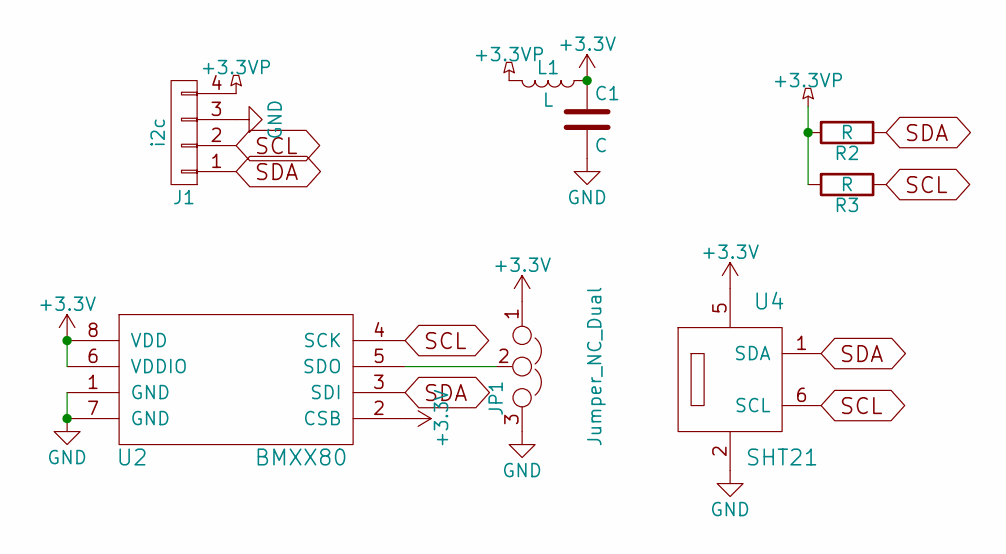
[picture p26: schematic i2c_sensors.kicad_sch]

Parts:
C1: C; C_0805
J1: i2c; Pin_Header_Straight_1x04_Pitch2.54mm
JP1: Jumper_NC_Dual; Pin_Header_Straight_1x03_Pitch2.54mm
L1: L; L_0805
R2, R3: R; R_0805
U2: BMXX80; BME280
U4: SHT21; DFN-6-1EP_3x3mm_Pitch0.95mm

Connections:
+3.3VP: J1.4, L1.2, R2.2, R3.2
+3V3: C1.1, JP1.1, L1.1, U2.2 (CSB), U2.6 (VDDIO), U2.8 (VDD), U4.5
GND: C1.2, J1.3, JP1.3, U2.1 (GND), U2.7 (GND), U4.2
unnamed: JP1.2, U2.5 (SDO)
SCL: J1.2, R3.1, U2.4 (SCK), U4.6 (SCL)
SDA: J1.1, R2.1, U2.3 (SDI), U4.1 (SDA)

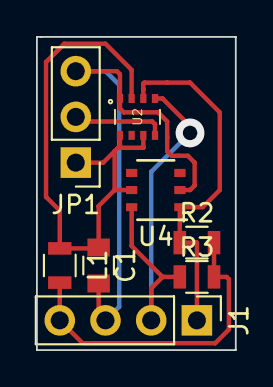
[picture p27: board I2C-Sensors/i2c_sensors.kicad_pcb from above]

Board: 2 copper layers, 11.0 x 17.4 mm, 8 parts (0 on the bottom side), 6 nets.

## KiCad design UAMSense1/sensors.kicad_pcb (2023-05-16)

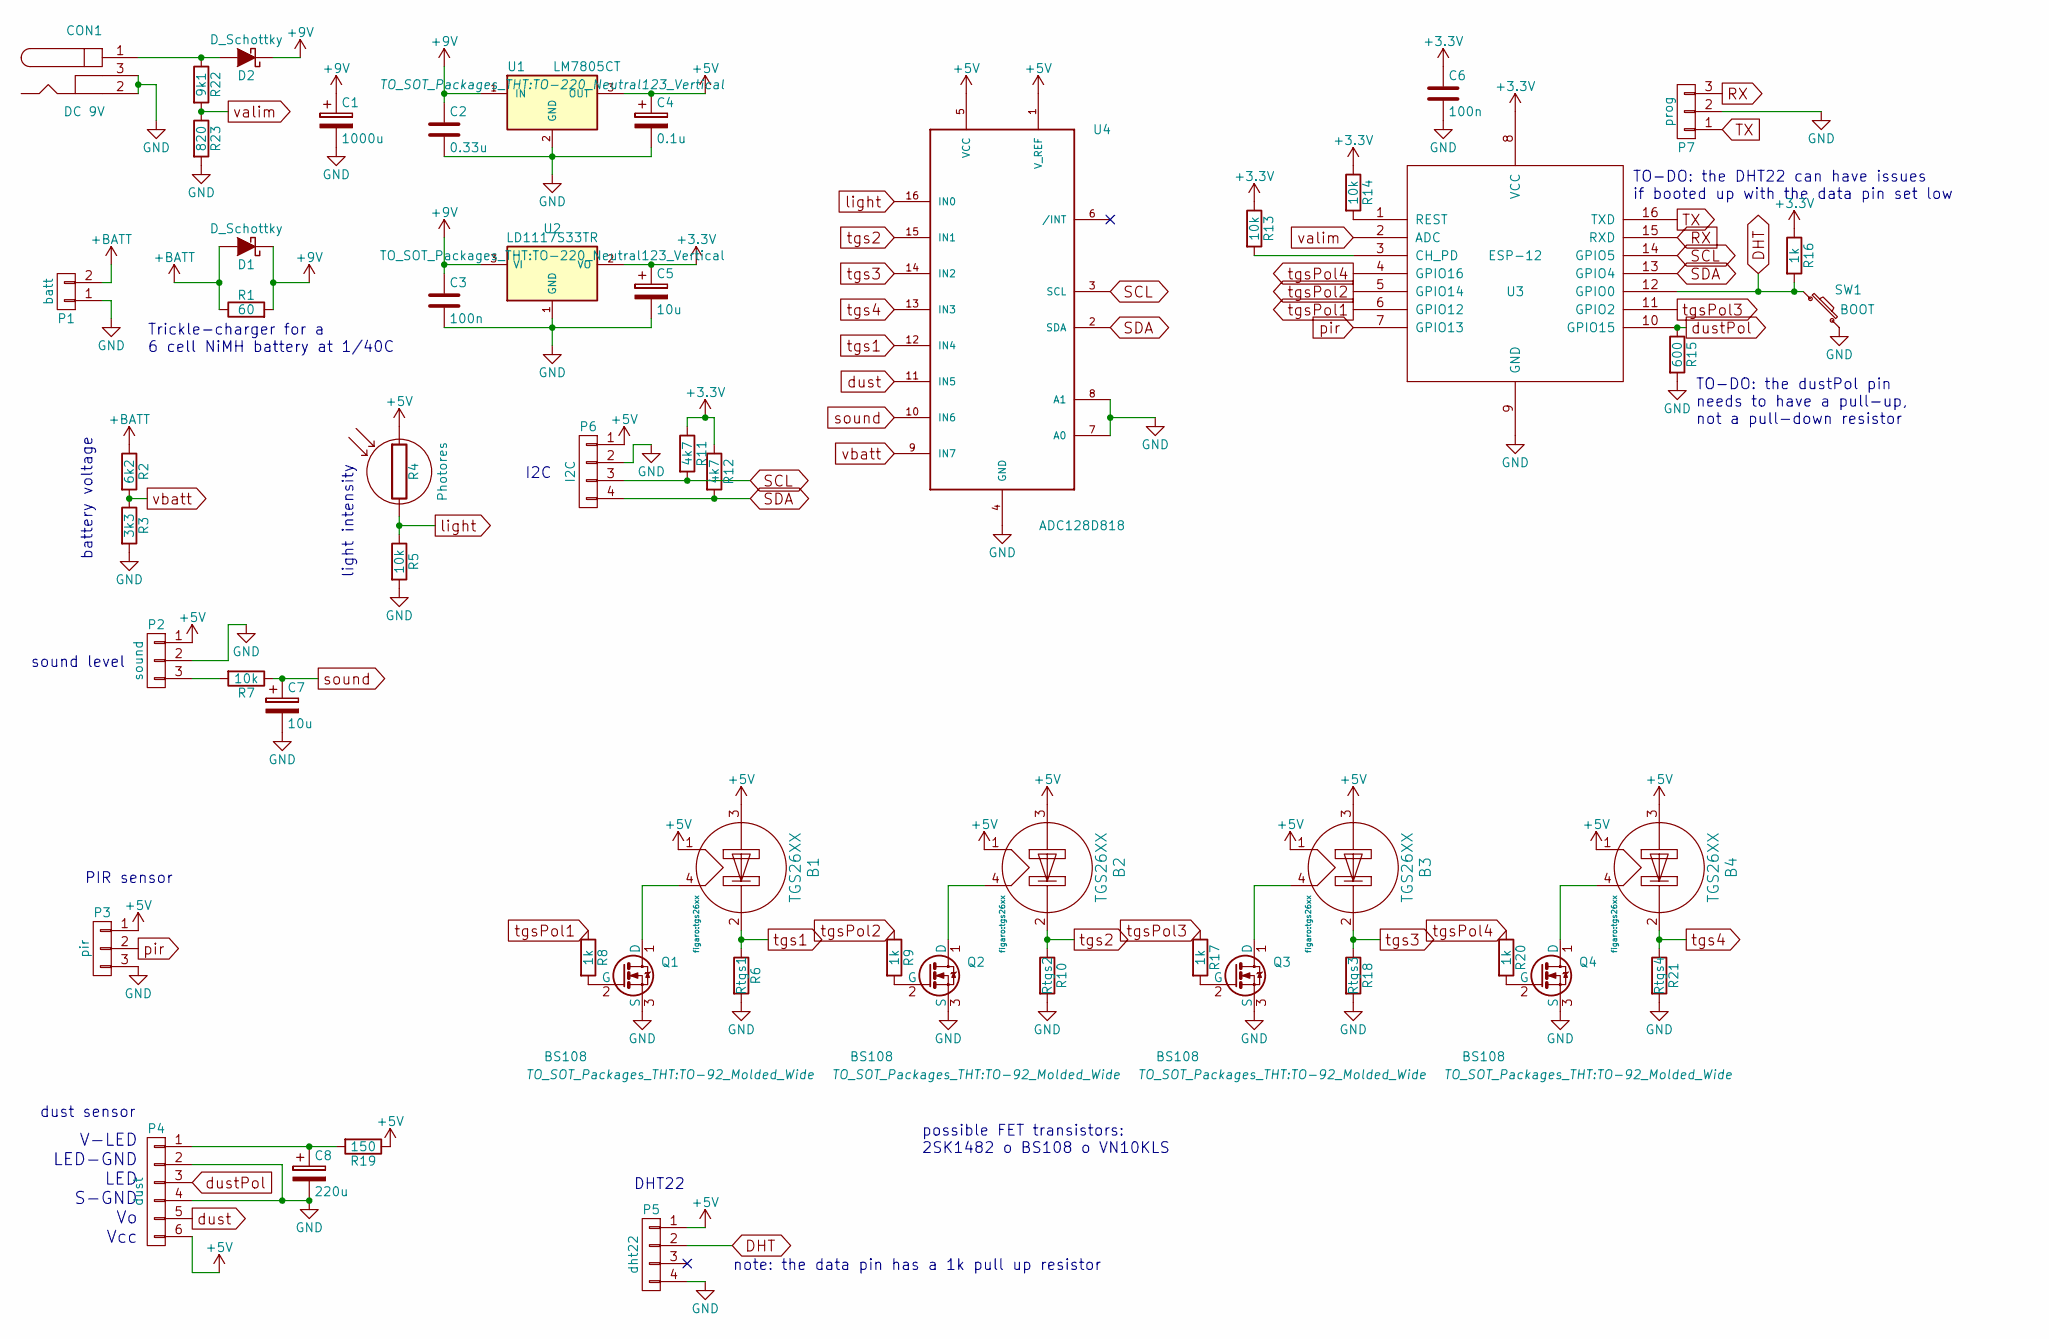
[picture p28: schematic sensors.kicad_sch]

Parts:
B1, B2, B3, B4: TGS26XX; tgs26xx
C1: 1000u; C_Radial_D10_L16_P5
C2: 0.33u; C_Rect_L7_W2_P5
C3: 100n; C_Rect_L7_W2_P5
C4: 0.1u; C_Radial_D8_L11.5_P3.5
C5, C7: 10u; C_Radial_D8_L11.5_P3.5
C6: 100n; C_Rect_L13_W4_P10
C8: 220u; C_Radial_D8_L11.5_P3.5
CON1: DC 9V; JACK_ALIM
D1, D2: D_Schottky; Diode_DO-41_SOD81_Vertical_KathodeUp
P1: batt; Pin_Header_Straight_1x02
P2: sound; Socket_Strip_Straight_1x03
P3: pir; Socket_Strip_Straight_1x03
P4: dust; Pin_Header_Straight_1x06
P5: dht22; Socket_Strip_Straight_1x04
P6: I2C; Socket_Strip_Straight_1x04
P7: prog; Pin_Header_Straight_1x03
Q1, Q2, Q3, Q4: BS108; TO-92_Molded_Wide
R1: 60; Resistor_Horizontal_RM20mm
R2: 6k2; Resistor_Horizontal_RM15mm
R3: 3k3; Resistor_Horizontal_RM15mm
R4: Photores; Resistor_Cement_Vertical_LargePads_KOA-BGR-5N-7N
R5, R7, R13, R14: 10k; Resistor_Horizontal_RM15mm
R6: Rtgs1; Resistor_Horizontal_RM15mm
R8, R9, R16, R17, R20: 1k; Resistor_Horizontal_RM15mm
R10: Rtgs2; Resistor_Horizontal_RM15mm
R11, R12: 4k7; Resistor_Horizontal_RM15mm
R15: 600; Resistor_Horizontal_RM15mm
R18: Rtgs3; Resistor_Horizontal_RM15mm
R19: 150; Resistor_Horizontal_RM15mm
R21: Rtgs4; Resistor_Horizontal_RM15mm
R22: 9k1; Resistor_Horizontal_RM15mm
R23: 820; Resistor_Horizontal_RM15mm
SW1: BOOT; SW_PUSH_SMALL
U1: LM7805CT; TO-220_Neutral123_Vertical
U2: LD1117S33TR; TO-220_Neutral123_Vertical
U3: ESP-12
U4: ADC128D818; SSOP-16_4.4x5.2mm_Pitch0.65mm

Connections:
+3V3: C5.1, C6.1, R11.1, R12.1, R13.1, R14.1, R16.1, U2.2 (VO), U3.8 (VCC)
+5V: B1.1, B1.3, B2.1, B2.3, B3.1, B3.3, B4.1, B4.3, C4.1, P2.1, P3.1, P4.6, P5.1, P6.1, R4.1, R19.1, U1.3 (OUT), U4.1 (V_REF), U4.5 (VCC)
+9V: C1.1, C2.1, C3.1, D1.1 (K), D2.1 (K), R1.2, U1.1 (IN), U2.3 (VI)
+BATT: D1.2 (A), P1.2, R1.1, R2.1
DHT: P5.2, R16.2, SW1.1, U3.12 (GPIO0)
GND: C1.2, C2.2, C3.2, C4.2, C5.2, C6.2, C7.2, C8.2, CON1.2, CON1.3, P1.1, P2.2, P3.3, P4.2, P4.4, P5.4, P6.2, P7.2, Q1.3 (S), Q2.3 (S), Q3.3 (S), Q4.3 (S), R3.2, R5.2, R6.2, R10.2, R15.2, R18.2, R21.2, R23.2, SW1.2, U1.2 (GND), U2.1 (GND), U3.9 (GND), U4.4 (GND), U4.7 (A0), U4.8 (A1)
unnamed: B1.4, Q1.1 (D)
unnamed: B2.4, Q2.1 (D)
unnamed: B3.4, Q3.1 (D)
unnamed: B4.4, Q4.1 (D)
unnamed: C8.1, P4.1, R19.2
unnamed: CON1.1, D2.2 (A), R22.1
unnamed: P2.3, R7.2
unnamed: Q1.2 (G), R8.2
unnamed: Q2.2 (G), R9.2
unnamed: Q3.2 (G), R17.2
unnamed: Q4.2 (G), R20.2
unnamed: R13.2, U3.3 (CH_PD)
unnamed: R14.2, U3.1 (REST)
RX: P7.3, U3.15 (RXD)
SCL: P6.3, R11.2, U3.14 (GPIO5), U4.3 (SCL)
SDA: P6.4, R12.2, U3.13 (GPIO4), U4.2 (SDA)
TX: P7.1, U3.16 (TXD)
dust: P4.5, U4.11 (IN5)
dustPol: P4.3, R15.1, U3.10 (GPIO15)
light: R4.2, R5.1, U4.16 (IN0)
pir: P3.2, U3.7 (GPIO13)
sound: C7.1, R7.1, U4.10 (IN6)
tgs1: B1.2 (-), R6.1, U4.12 (IN4)
tgs2: B2.2 (-), R10.1, U4.15 (IN1)
tgs3: B3.2 (-), R18.1, U4.14 (IN2)
tgs4: B4.2 (-), R21.1, U4.13 (IN3)
tgsPol1: R8.1, U3.6 (GPIO12)
tgsPol2: R9.1, U3.5 (GPIO14)
tgsPol3: R17.1, U3.11 (GPIO2)
tgsPol4: R20.1, U3.4 (GPIO16)
valim: R22.2, R23.1, U3.2 (ADC)
vbatt: R2.2, R3.1, U4.9 (IN7)

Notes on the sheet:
I2C
dust sensor
TO-DO: the dustPol pin needs to have a pull-up, not a pull-down resistor
Trickle-charger for a 6 cell NiMH battery at 1/40C
note: the data pin has a 1k pull up resistor
sound level
TO-DO: the DHT22 can have issues if booted up with the data pin set low
possible FET transistors: 2SK1482 o BS108 o VN10KLS
PIR sensor
DHT22
V-LED LED-GND LED S-GND Vo Vcc
battery voltage
light intensity

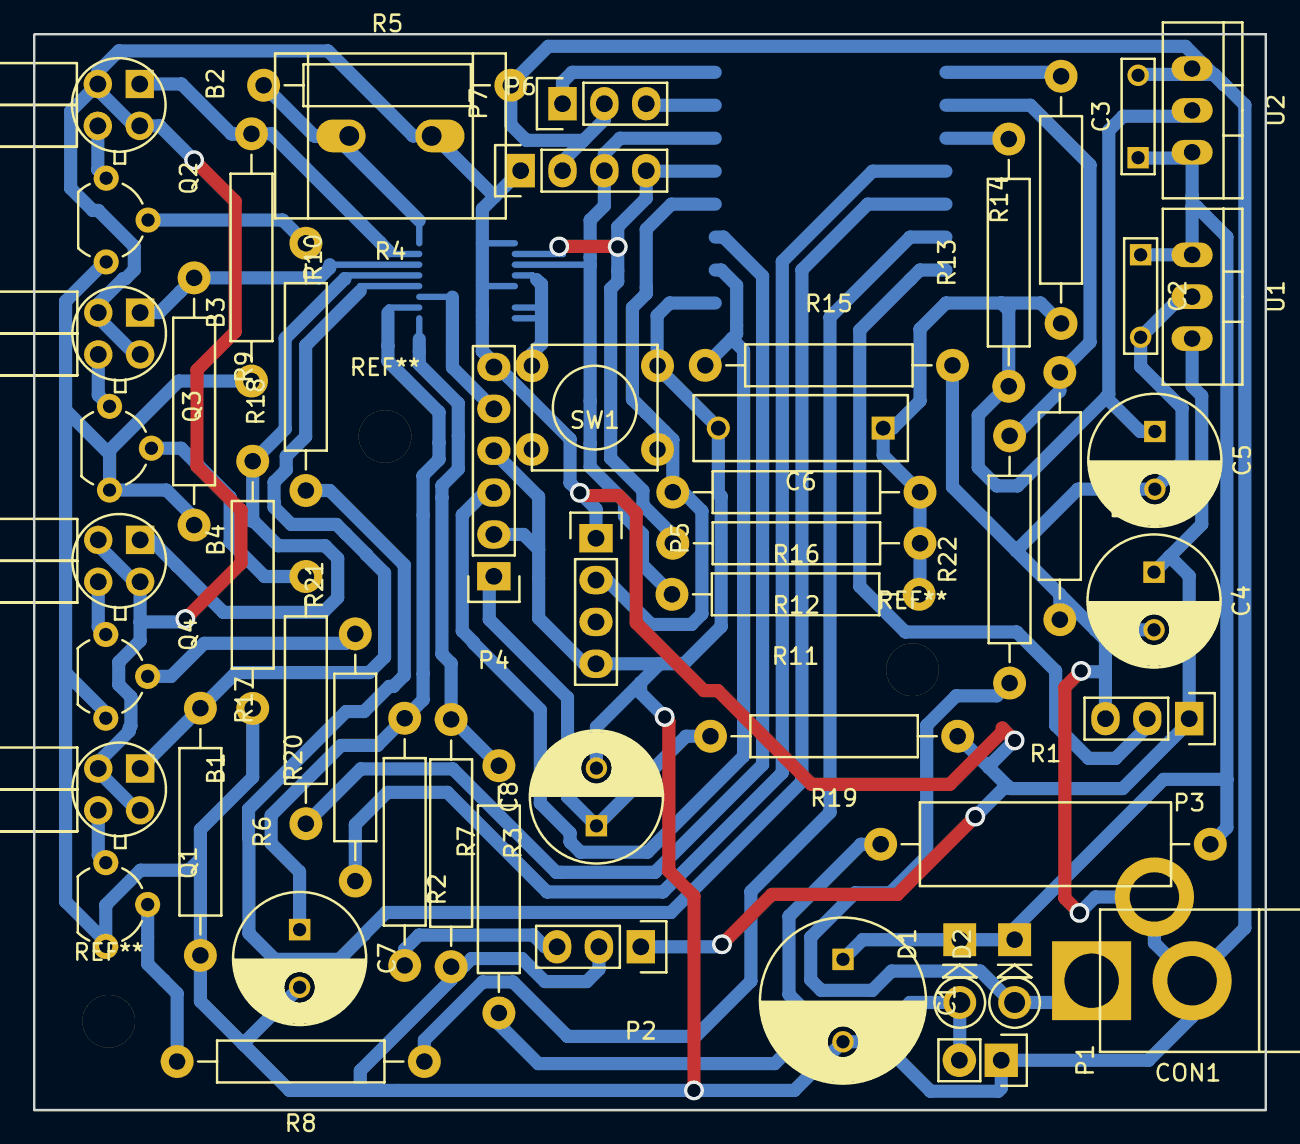
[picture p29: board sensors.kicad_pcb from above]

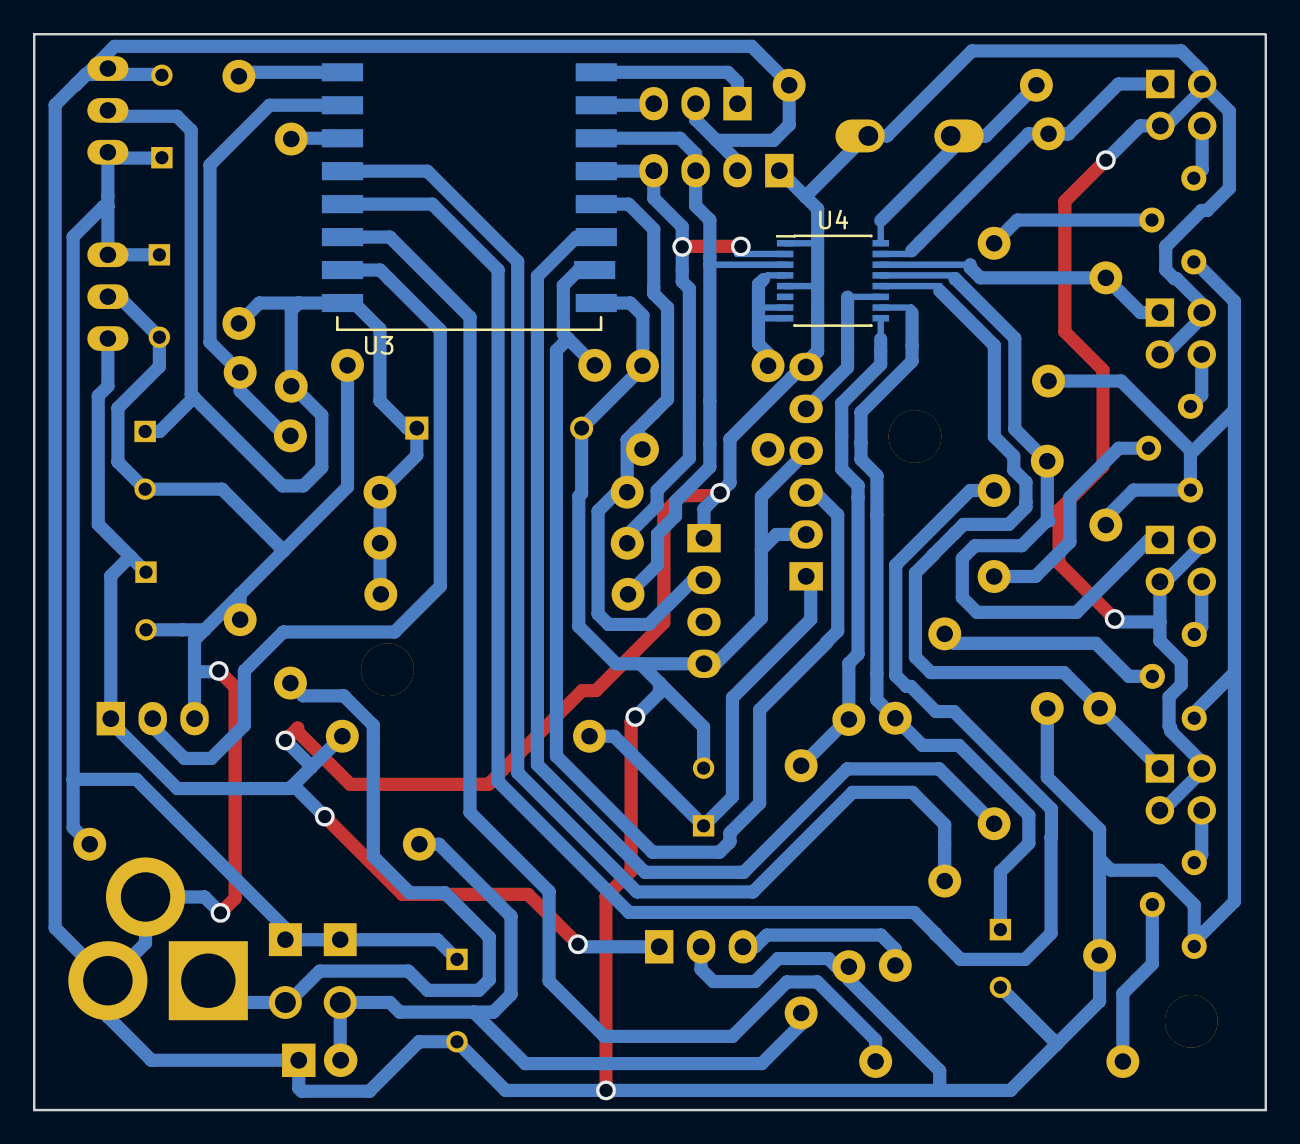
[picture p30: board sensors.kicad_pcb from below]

Board: 2 copper layers, 74.7 x 65.3 mm, 54 parts (2 on the bottom side), 38 nets.

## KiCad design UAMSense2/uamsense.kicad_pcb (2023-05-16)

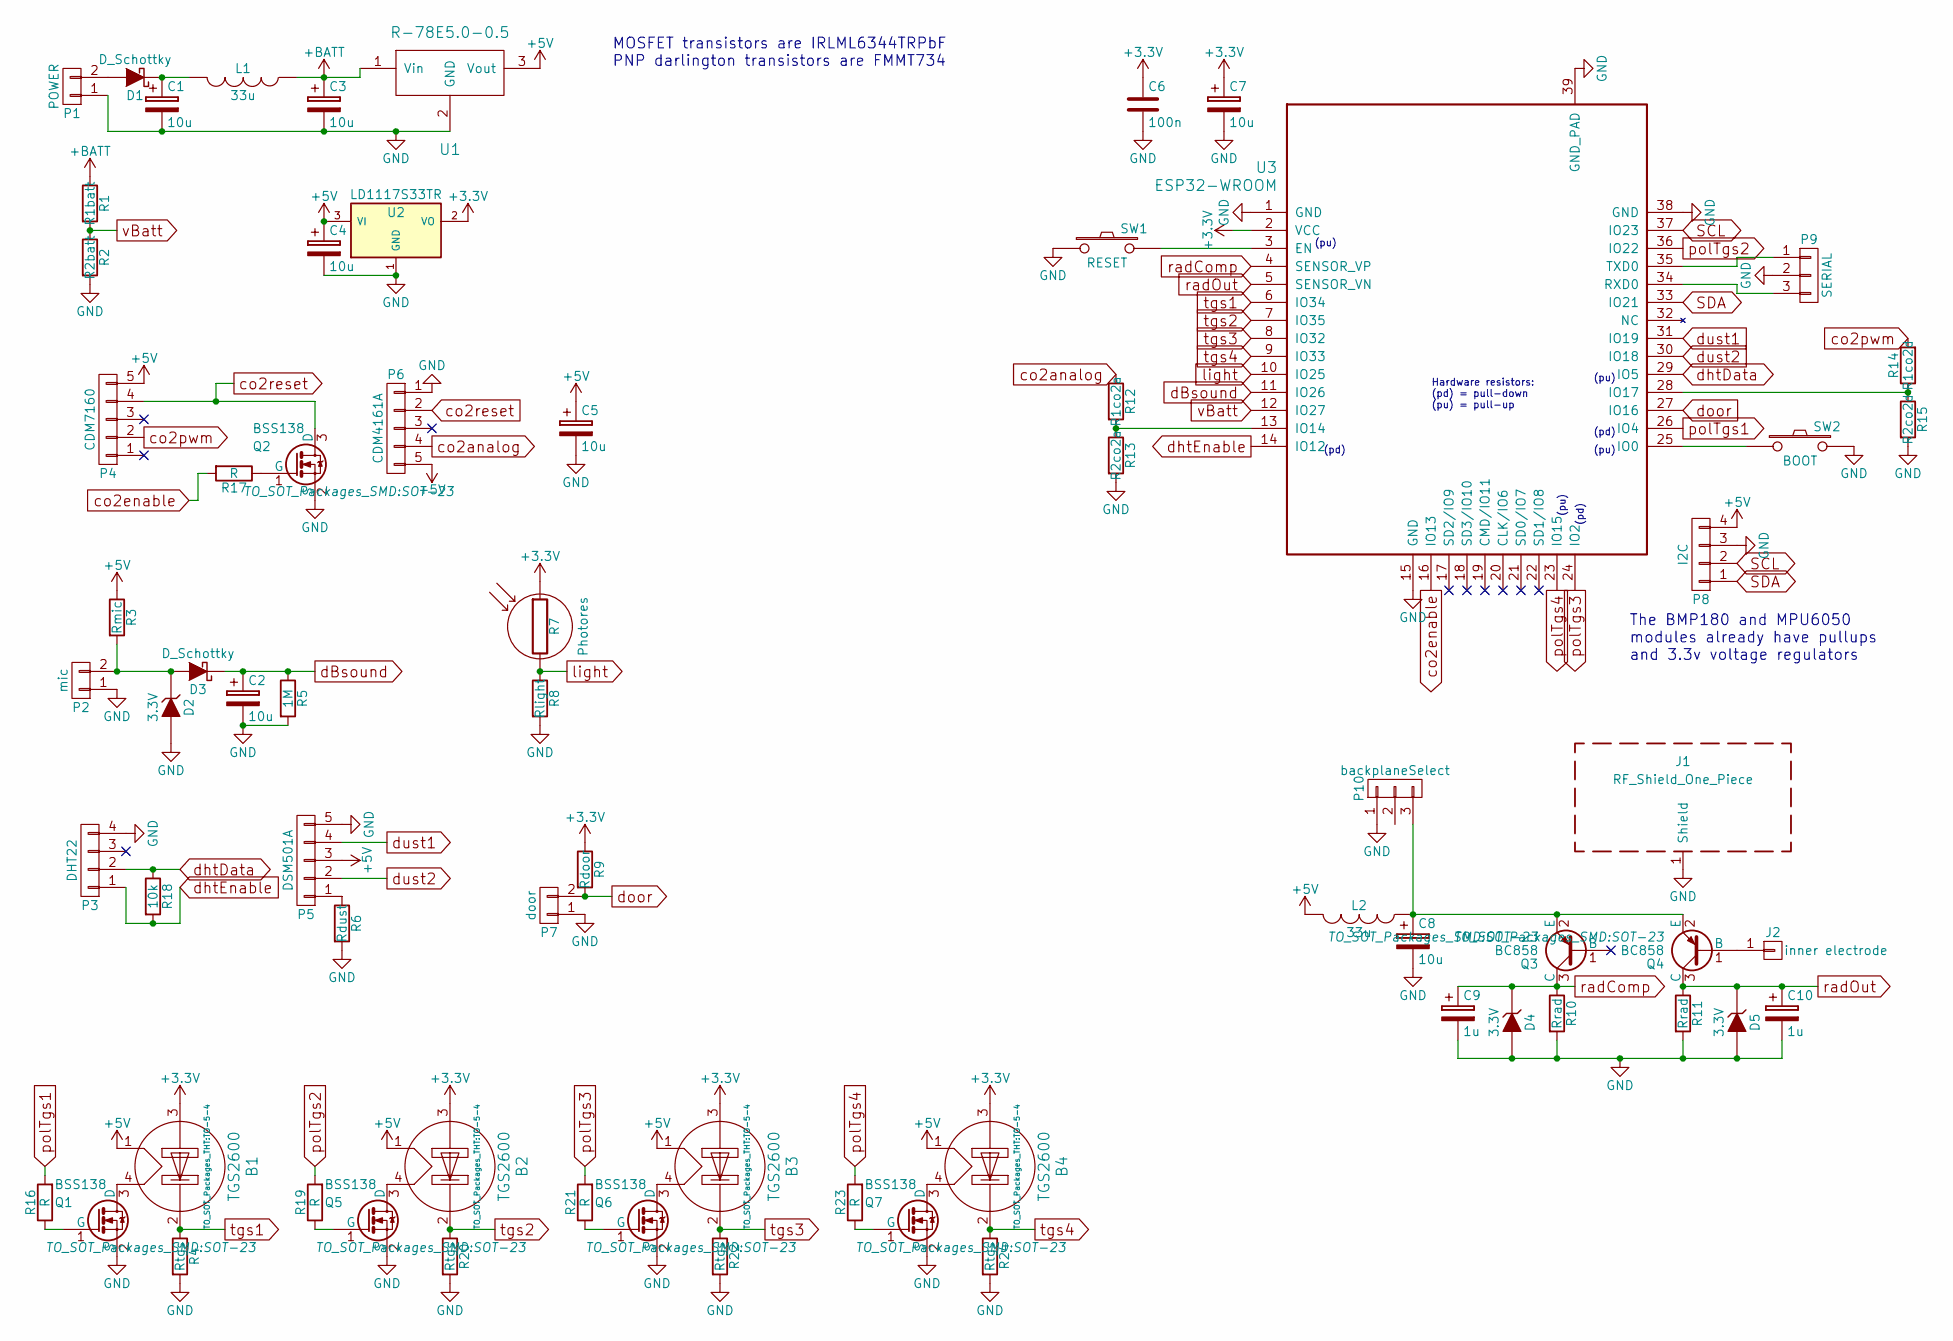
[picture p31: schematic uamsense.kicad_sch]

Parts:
B1, B2, B3, B4: TGS2600; TO-5-4
C1, C2, C3, C4, C5, C7, C8: 10u; C_1206
C6: 100n; C_0805
C9, C10: 1u; C_0805
D1, D3: D_Schottky; D_SMA_Standard
D2, D4, D5: 3.3V; D_1206
J1: RF_Shield_One_Piece; Laird_Technologies_BMI-S-107_44.37x44.37mm
J2: inner electrode; Measurement_Point_Round-SMD-Pad_Small
L1, L2: 33u; Neosid_Inductor_SM-NE30_SMD1210
P1: POWER; TerminalBlock_Pheonix_MPT-2.54mm_2pol
P2: mic; Socket_Strip_Straight_1x02_Pitch2.54mm
P3: DHT22; Socket_Strip_Straight_1x04_Pitch2.54mm
P4: CDM7160; Socket_Strip_Straight_1x05_Pitch2.54mm
P5: DSM501A; Socket_Strip_Straight_1x05_Pitch2.54mm
P6: CDM4161A; Socket_Strip_Angled_1x05_Pitch2.54mm
P7: door; TerminalBlock_Pheonix_MPT-2.54mm_2pol
P8: I2C; Socket_Strip_Straight_1x04_Pitch2.54mm
P9: SERIAL; Pin_Header_Straight_1x03_Pitch2.54mm
P10: backplaneSelect; Pin_Header_Straight_1x03_Pitch2.54mm
Q1, Q2, Q5, Q6, Q7: BSS138; SOT-23
Q3, Q4: BC858; SOT-23
R1: R1batt; R_0805
R2: R2batt; R_0805
R3: Rmic; R_0805
R4, R20, R22, R24: Rtgs; Resistor_SMD+THTuniversal_0805to1206_RM10_HandSoldering
R5: 1M; R_0805
R6: Rdust; R_0805
R7: Photores; R_Radial_Power_L12.0mm_W8.0mm_P5.00mm
R8: Rlight; R_0805
R9: Rdoor; R_0805
R10, R11: Rrad; R_0805
R12: R1co2a; R_0805
R13: R2co2a; R_0805
R14: R1co2d; R_0805
R15: R2co2d; R_0805
R16, R17, R19, R21, R23: R; R_0805
R18: 10k; R_0805
SW1: RESET; SW_SPST_EVQQ2
SW2: BOOT; SW_SPST_EVQQ2
U1: R-78E5.0-0.5
U2: LD1117S33TR; SOT-223
U3: ESP32-WROOM

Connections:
+3V3: B1.3, B2.3, B3.3, B4.3, C6.1, C7.1, R7.1, R9.1, U2.2 (VO), U3.2 (VCC)
+5V: B1.1, B2.1, B3.1, B4.1, C4.1, C5.1, L2.2, P4.5, P5.3, P6.5, P8.4, R3.1, U1.3 (Vout), U2.3 (VI)
+BATT: C3.1, L1.1, R1.1, U1.1 (Vin)
GND: C1.2, C2.2, C3.2, C4.2, C5.2, C6.2, C7.2, C8.2, C9.2, C10.2, D2.2 (A), D4.2 (A), D5.2 (A), J1.1, P1.1, P2.1, P3.4, P5.5, P6.1, P7.1, P8.3, P9.2, P10.1, Q1.2 (S), Q2.2 (S), Q5.2 (S), Q6.2 (S), Q7.2 (S), R2.2, R4.2, R5.2, R6.2, R8.2, R10.2, R11.2, R13.2, R15.2, R20.2, R22.2, R24.2, SW1.1, SW2.2, U1.2 (GND), U2.1 (GND), U3.1 (GND), U3.15 (GND), U3.38 (GND), U3.39 (GND_PAD)
unnamed: B1.4, Q1.3 (D)
unnamed: B2.4, Q5.3 (D)
unnamed: B3.4, Q6.3 (D)
unnamed: B4.4, Q7.3 (D)
unnamed: C1.1, D1.1 (K), L1.2
unnamed: C8.1, L2.1, P10.3, Q3.2 (E), Q4.2 (E)
unnamed: D1.2 (A), P1.2
unnamed: D2.1 (K), D3.2 (A), P2.2, R3.2
unnamed: J2.1, Q4.1 (B)
unnamed: P5.1, R6.1
unnamed: P9.1, U3.35 (TXD0)
unnamed: P9.3, U3.34 (RXD0)
unnamed: Q1.1 (G), R16.1
unnamed: Q2.1 (G), R17.1
unnamed: Q5.1 (G), R19.1
unnamed: Q6.1 (G), R21.1
unnamed: Q7.1 (G), R23.1
unnamed: R12.2, R13.1, U3.13 (IO14)
unnamed: R14.1, R15.1, U3.28 (IO17)
unnamed: SW1.2, U3.3 (EN)
unnamed: SW2.1, U3.25 (IO0)
SCL: P8.2, U3.37 (IO23)
SDA: P8.1, U3.33 (IO21)
co2analog: P6.4, R12.1
co2enable: R17.2, U3.16 (IO13)
co2pwm: P4.2, R14.2
co2reset: P4.4, P6.2, Q2.3 (D)
dBsound: C2.1, D3.1 (K), R5.1, U3.11 (IO26)
dhtData: P3.2, R18.1, U3.29 (IO5)
dhtEnable: P3.1, R18.2, U3.14 (IO12)
door: P7.2, R9.2, U3.27 (IO16)
dust1: P5.4, U3.31 (IO19)
dust2: P5.2, U3.30 (IO18)
light: R7.2, R8.1, U3.10 (IO25)
polTgs1: R16.2, U3.26 (IO4)
polTgs2: R19.2, U3.36 (IO22)
polTgs3: R21.2, U3.24 (IO2)
polTgs4: R23.2, U3.23 (IO15)
radComp: C9.1, D4.1 (K), Q3.3 (C), R10.1, U3.4 (SENSOR_VP)
radOut: C10.1, D5.1 (K), Q4.3 (C), R11.1, U3.5 (SENSOR_VN)
tgs1: B1.2 (-), R4.1, U3.6 (IO34)
tgs2: B2.2 (-), R20.1, U3.7 (IO35)
tgs3: B3.2 (-), R22.1, U3.8 (IO32)
tgs4: B4.2 (-), R24.1, U3.9 (IO33)
vBatt: R1.2, R2.1, U3.12 (IO27)

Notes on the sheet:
Hardware resistors: (pd) = pull-down (pu) = pull-up
(pu)
The BMP180 and MPU6050 modules already have pullups and 3.3v voltage regulators
(pd)
MOSFET transistors are IRLML6344TRPbF PNP darlington transistors are FMMT734

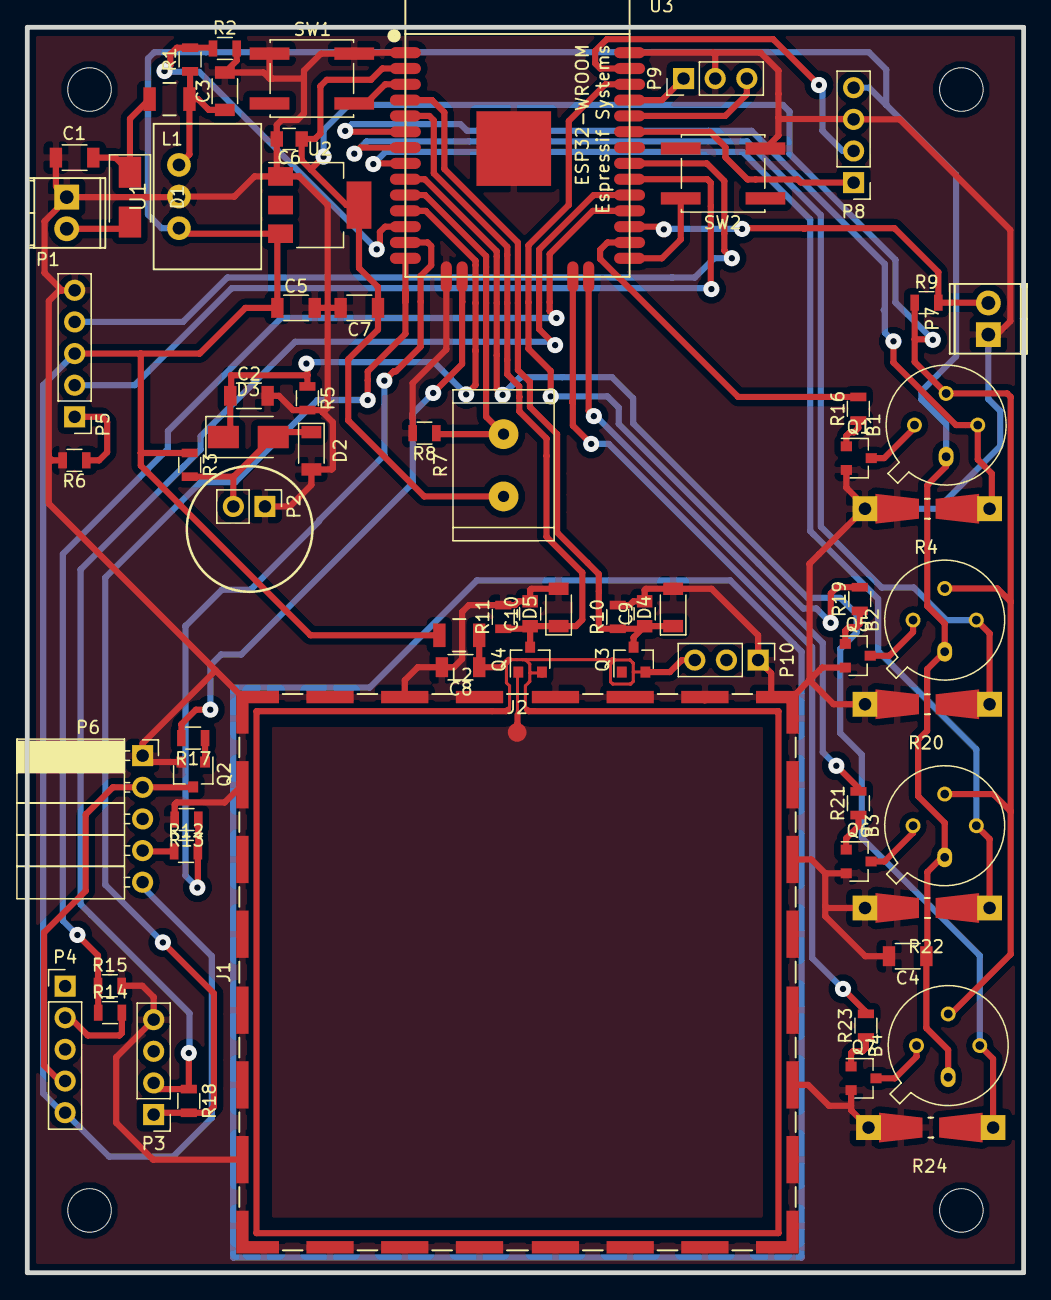
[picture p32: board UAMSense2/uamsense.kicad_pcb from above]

Board: 2 copper layers, 80.0 x 100.0 mm, 69 parts (0 on the bottom side), 49 nets.

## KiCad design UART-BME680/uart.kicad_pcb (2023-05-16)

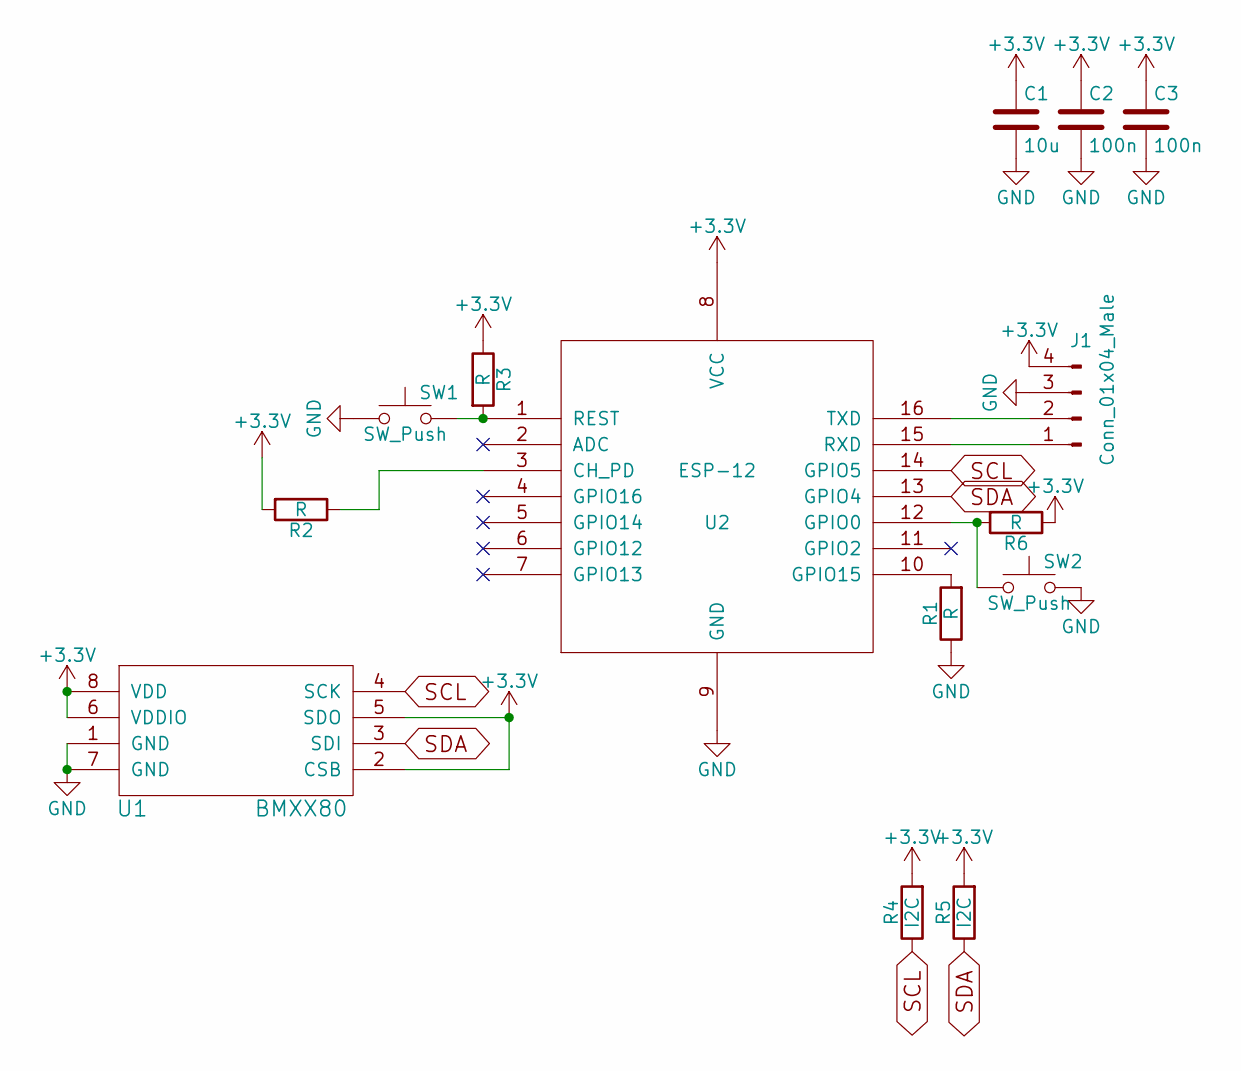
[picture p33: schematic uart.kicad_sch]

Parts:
C1: 10u; C_1206_HandSoldering
C2, C3: 100n; C_0805_HandSoldering
J1: Conn_01x04_Male; Pin_Header_Angled_1x04_Pitch2.54mm
R1, R2, R3, R6: R; R_0805_HandSoldering
R4, R5: I2C; R_0805_HandSoldering
SW1, SW2: SW_Push; smd_button
U1: BMXX80; BME280
U2: ESP-12

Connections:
+3V3: C1.1, C2.1, C3.1, J1.4, R2.2, R3.1, R4.2, R5.2, R6.1, U1.2 (CSB), U1.5 (SDO), U1.6 (VDDIO), U1.8 (VDD), U2.8 (VCC)
GND: C1.2, C2.2, C3.2, J1.3, R1.1, SW1.1, SW2.2, U1.1 (GND), U1.7 (GND), U2.9 (GND)
unnamed: J1.1, U2.15 (RXD)
unnamed: J1.2, U2.16 (TXD)
unnamed: R1.2, U2.10 (GPIO15)
unnamed: R2.1, U2.3 (CH_PD)
unnamed: R3.2, SW1.2, U2.1 (REST)
unnamed: R6.2, SW2.1, U2.12 (GPIO0)
SCL: R4.1, U1.4 (SCK), U2.14 (GPIO5)
SDA: R5.1, U1.3 (SDI), U2.13 (GPIO4)

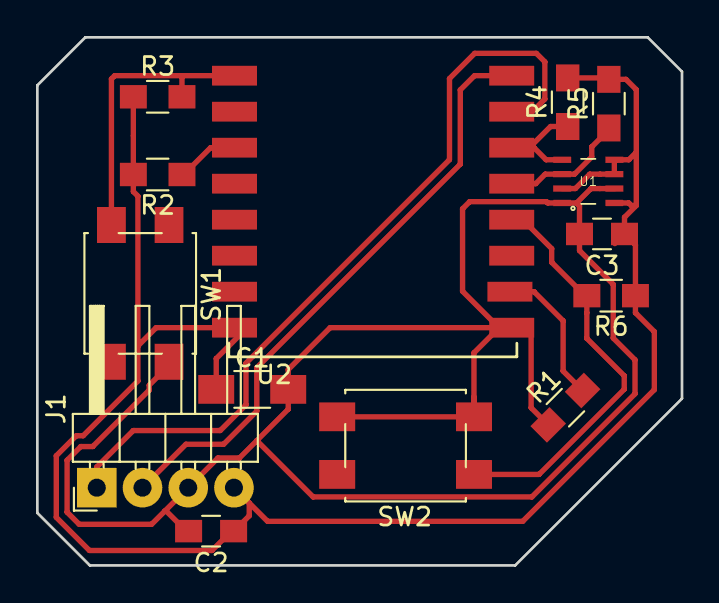
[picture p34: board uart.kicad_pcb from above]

Board: 2 copper layers, 35.8 x 29.3 mm, 14 parts (0 on the bottom side), 10 nets.

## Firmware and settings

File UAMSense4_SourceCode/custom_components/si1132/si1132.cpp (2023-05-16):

#include "esphome/core/log.h"
#include "si1132.h"
#include "esphome/core/hal.h"

// BASED ON https://github.com/FaBoPlatform/FaBoUV-Si1132-Library/tree/master/src

/** si1132 Slave Address register */
#define SI1132_SLAVE_ADDRESS 0x60
/** Who_am_i register */
#define SI1132_WHO_AM_I_REG 0x00
/** Device check register */
#define SI1132_DEVICE 0x32

/** HW_KEY register */
#define SI1132_HW_KEY_REG 0x07
/** MEASRATE0 register */
#define SI1132_MEASRATE0_REG 0x08
/** MEASRATE1 register */
#define SI1132_MEASRATE1_REG 0x09
/** UCOEF0 register */
#define SI1132_UCOEF0_REG 0x13
/** UCOEF1 register */
#define SI1132_UCOEF1_REG 0x14
/** UCOEF2 register */
#define SI1132_UCOEF2_REG 0x15
/** UCOEF3 register */
#define SI1132_UCOEF3_REG 0x16
/** PARAM_WR register */
#define SI1132_PARAM_WR_REG 0x17
/** Command register */
#define SI1132_COMMAND_REG 0x18
/** Visible Data register */
#define SI1132_VISIBLE_DATA_REG 0x22
/** IR Data register */
#define SI1132_IR_DATA_REG 0x24
/** Auxiliary Data register */
#define SI1132_AUX_DATA_REG 0x2C

/** Chip list Parameter RAM Offset */
#define SI1132_CHIPLIST_PARAM_OFFSET 0x01
/** ALS Encoding Parameter RAM Offset */
#define SI1132_ALS_ENCODING_PARAM_OFFSET 0x06
/** ALS VIS ADC Counter register */
#define SI1132_ALS_VIS_ADC_COUNTER_PARAM_OFFSET 0x10
/** ALS VIS ADC Gain Parameter RAM Offset */
#define SI1132_ALS_VIS_ADC_GAIN_PARAM_OFFSET 0x11
/** ALS VIS ADC Misc Parameter RAM Offset */
#define SI1132_ALS_VIS_ADC_MISC_PARAM_OFFSET 0x12
/** ALS IR ADC Counter  Parameter RAM Offset */
#define SI1132_ALS_IR_ADC_COUNTER_PARAM_OFFSET 0x1D
/** ALS IR ADC Gain  Parameter RAM Offset */
#define SI1132_ALS_IR_ADC_GAIN_PARAM_OFFSET 0x1E
/** ALS IR ADC Misc  Parameter RAM Offset */
#define SI1132_ALS_IR_ADC_MISC_PARAM_OFFSET 0x1F
/** ALS IR Adcmux  Parameter RAM Offset */
#define SI1132_ALS_IR_ADCMUX_PARAM_OFFSET 0x0E
/** Auxiliary Adcmux  Parameter RAM Offset */
#define SI1132_AUX_ADCMUX_PARAM_OFFSET 0x0F

/** Enables UV Index register */
#define SI1132_EN_UV      0b10000000
/** Enables Auxiliary Channel register */
#define SI1132_EN_AUX     0b01000000
/** Enables ALS IR Channel register */
#define SI1132_EN_ALS_IR  0b00100000
/** Enables ALS Visible Channel register */
#define SI1132_EN_ALS_VIS 0b00010000

/** ALS　VIS ALIGN register */
#define SI1132_ALS_VIS_ALIGN 0b00010000
/** ALS　IR ALIGN register */
#define SI1132_ALS_IR_ALIGN  0b00100000

/** ADC Clock 1 : 50 ns times */
#define SI1132_1_ADC_CLOCK   0b00000000
/** ADC Clock 7 : 350 ns times */
#define SI1132_7_ADC_CLOCK   0b00010000
/** ADC Clock 15 : 750 ns times */
#define SI1132_15_ADC_CLOCK  0b00100000
/** ADC Clock 31 : 1.15 us times */
#define SI1132_31_ADC_CLOCK  0b00110000
/** ADC Clock 63 : 3.15 us times */
#define SI1132_63_ADC_CLOCK  0b01000000
/** ADC Clock 127 : 6.35 us times */
#define SI1132_127_ADC_CLOCK 0b10100000
/** ADC Clock 255 : 12.75 us times */
#define SI1132_255_ADC_CLOCK 0b01100000
/** ADC Clock 511 : 25.55 us times */
#define SI1132_511_ADC_CLOCK 0b01110000

/** Divided ADC Clock 1 */
#define SI1132_1_DIVIDED_ADC_CLOCK  0b0000000
/** Divided ADC Clock 16 */
#define SI1132_16_DIVIDED_ADC_CLOCK 0b0000100
/** Divided ADC Clock 32 */
#define SI1132_32_DIVIDED_ADC_CLOCK 0b0000101
/** Divided ADC Clock 64 */
#define SI1132_64_DIVIDED_ADC_CLOCK 0b0000110

/** Normal single range */
#define SI1132_NORMAL_SIGNAL_RANGE 0b00000000
/** High single range */
#define SI1132_HIGH_SIGNAL_RANGE   0b00100000

/** ALS IR Adcmux SMALLIR */
#define SI1132_ALS_IR_ADCMUX_SMALLIR 0x00

/** ALS IR Adcmux Temperature */
#define SI1132_AUX_ADCMUX_TEMPERATURE 0x65
/** Auxiliary ADCMUX VDD */
#define SI1132_AUX_ADCMUX_VDD 0x75

/** Command ALS Auto */
#define SI1132_COMMAND_ALS_AUTO 0x0E
/** Command ALS force */
#define SI1132_COMMAND_ALS_FORCE 0x06
/** Command Reset */
#define SI1132_COMMAND_RESET 0x01
/** HW_KEY Default Value */
#define SI1132_HW_KEY_DEFAULT 0x17

/** Normal single range */
#define SI1132_PARAM_QUERY 0b10000000
/** High single range */
#define SI1132_PARAM_SET   0b10100000


namespace esphome {
namespace si1132 {

static const char *TAG = "si1132.sensor";

float SI1132Component::get_setup_priority() const { return setup_priority::DATA; }

void SI1132Component::setup(){
  // Reset
  this->write_byte(SI1132_COMMAND_REG, SI1132_COMMAND_RESET);
  delay(1);
  this->write_byte(0x22, 0x01);
  delay(100);
  
  // Select HW_KEY register
  this->write_byte(SI1132_HW_KEY_REG, SI1132_HW_KEY_DEFAULT);

  // SET PARAM_WR(Chiplist)
  this->write_byte(SI1132_PARAM_WR_REG, SI1132_EN_ALS_IR|SI1132_EN_ALS_VIS); // Add SI1132_EN_UV if you need the (bad) UV estimation
  // COMMAND(Set Chiplist)
  this->write_byte(SI1132_COMMAND_REG, SI1132_PARAM_SET|SI1132_CHIPLIST_PARAM_OFFSET);

  // Rate setting
  //this->write_byte(SI1132_MEASRATE1_REG, 0x0);
  ///////////////////////////this->write_byte(SI1132_MEASRATE0_REG, 0x10);//ff);

  // SET PARAM_WR(ALS_ENCODING)
  //this->write_byte(SI1132_PARAM_WR_REG, SI1132_ALS_VIS_ALIGN | SI1132_ALS_IR_ALIGN); // Uncomment to read LSBs from the 13 bit ADC
  //this->write_byte(SI1132_COMMAND_REG, SI1132_PARAM_SET|SI1132_ALS_ENCODING_PARAM_OFFSET);


  /* IR */
  // SET ALS_IR_ADC_COUNTER
  //this->write_byte(SI1132_PARAM_WR_REG, SI1132_511_ADC_CLOCK); // Set highest integration time (most sensitivity)
  //this->write_byte(SI1132_COMMAND_REG, SI1132_PARAM_SET|SI1132_ALS_IR_ADC_COUNTER_PARAM_OFFSET);

  // SET ALS_IR_ADC_GAIN
  this->write_byte(SI1132_PARAM_WR_REG, SI1132_16_DIVIDED_ADC_CLOCK);//SI1132_1_DIVIDED_ADC_CLOCK); // gain 128 is highest
  this->write_byte(SI1132_COMMAND_REG, SI1132_PARAM_SET|SI1132_ALS_IR_ADC_GAIN_PARAM_OFFSET);

  // SET ALS_IR_ADC_MISC
  //this->write_byte(SI1132_PARAM_WR_REG, SI1132_HIGH_SIGNAL_RANGE); // Uncomment to set "high signal range" mode for operation under direct sunlight
  //this->write_byte(SI1132_COMMAND_REG, SI1132_PARAM_SET|SI1132_ALS_IR_ADC_MISC_PARAM_OFFSET);

  // SET ALS_IR_ADCMUX
  //this->write_byte(SI1132_PARAM_WR_REG, SI1132_ALS_IR_ADCMUX_SMALLIR);
  //this->write_byte(SI1132_COMMAND_REG, SI1132_PARAM_SET|SI1132_ALS_IR_ADCMUX_PARAM_OFFSET);


  /* Visible */
  // SET ALS_VIS_ADC_COUNTER
  //this->write_byte(SI1132_PARAM_WR_REG, SI1132_511_ADC_CLOCK); // Set highest integration time (most sensitivity)
  //this->write_byte(SI1132_COMMAND_REG, SI1132_PARAM_SET|SI1132_ALS_VIS_ADC_COUNTER_PARAM_OFFSET);

  // SET ALS_VIS_ADC_GAIN
  this->write_byte(SI1132_PARAM_WR_REG, SI1132_32_DIVIDED_ADC_CLOCK);//SI1132_1_DIVIDED_ADC_CLOCK); // gain 128 is highest
  this->write_byte(SI1132_COMMAND_REG, SI1132_PARAM_SET|SI1132_ALS_VIS_ADC_GAIN_PARAM_OFFSET);

  // SET ALS_VIS_ADC_MISC
  //this->write_byte(SI1132_PARAM_WR_REG, SI1132_HIGH_SIGNAL_RANGE); // Uncomment to set "high signal range" mode for operation under direct sunlight
  //this->write_byte(SI1132_COMMAND_REG, SI1132_PARAM_SET|SI1132_ALS_VIS_ADC_MISC_PARAM_OFFSET);
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
